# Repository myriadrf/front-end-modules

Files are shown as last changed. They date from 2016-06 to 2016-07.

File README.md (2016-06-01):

# RF Front-end Modules

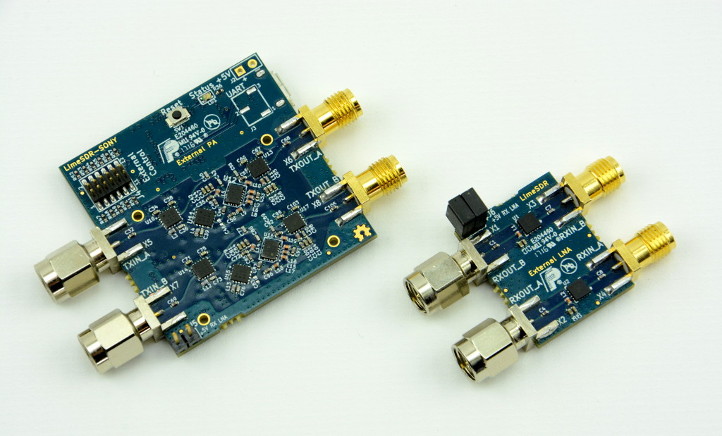
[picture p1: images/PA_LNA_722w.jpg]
Sony PA and TriQuint LNA boards


The [Front-end Modules project](https://myriadrf.org/projects/front-end-modules/) is concerned with creating RF front-end modules, such as PAs, LNAs and filters, that can be used together with an SDR platform in order to create a complete wireless solution.

## Contents

The directory structure is as follows:

      LimeSDR_PA_LNA/           
          firmware/              - firmware for Sony PA
          gui/                   - GUI for firmware PA
          hardware/              - design files for Sony PA and TriQuint LNA boards
          lms_vcp_drivers/       - Windows Virtual COM Port drivers for Sony PA board

      LimeSDR_SAW/<version>/
          BOM/                   - bill of materials spreadsheet
          DRC/                   - Design Rule Verification Report
          ERC/                   - Electrical Rule Check Report
          Gerber/                - Gerber CAM files
          NC Drill/              - Drill files
          Pick Place/            - Pick and place files         

## Licensing

### Hardware

The hardware designs are licensed under a Creative Commons Attribution 3.0 Unported licence.

### Firmware

All original code is provided under the Apache 2.0 License.

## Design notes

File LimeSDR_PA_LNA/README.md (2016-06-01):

# Sony PA and TriQuint LNA modules

## PA

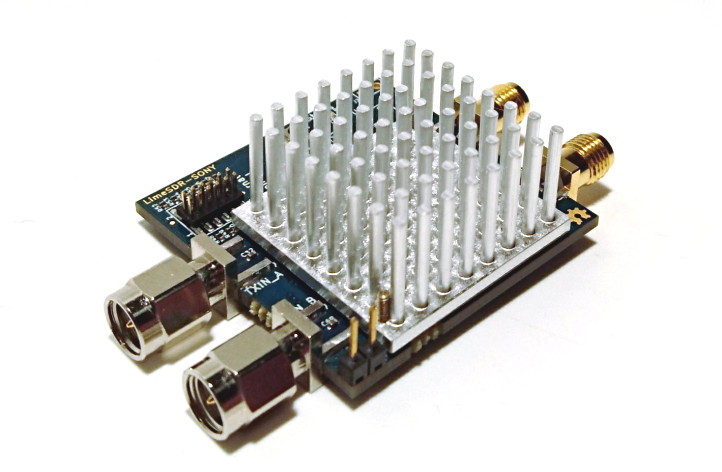
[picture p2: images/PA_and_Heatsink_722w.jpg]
Sony PA with heatsink fitted


## LNA 

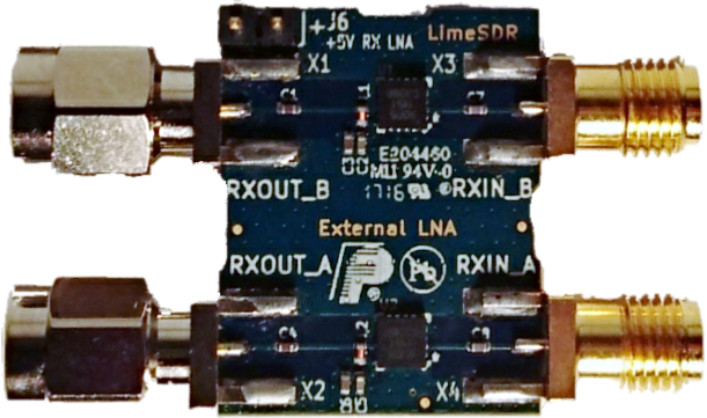
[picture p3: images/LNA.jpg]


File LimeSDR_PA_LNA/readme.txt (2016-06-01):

CONTENTS
========

   I. Description of folders and files

I. Description of folders and files
===================================

  readme.txt				- this file
  firmware/				- USB microcontroller related
   |- bin				- Contains compiled firmware image for USB microcontroller
   |- src				- Contains MCU firmware source files 
  gui/					- Software to control RF-qSpark v1.0 board
   |- paControl.exe			- GUI to control LimeSDR-Sony board
   |- src				- Contains GUI source files
   |- pa_setup                          - Contains SISO and Mode mode settings for PAs and Tuners at Frequencies (GHz): 0.5; 0.8; 1.0; 1.5; ;1.8; 2.1; 2.5; 2.7; 3.0; 3.3; 3.5; 3.8;
  lms_vcp_drivers/			- Windows Virtual COM Port drivers for LimeSDR-Sony board

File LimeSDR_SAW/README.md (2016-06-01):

# SAWNICS SAW filter modules 

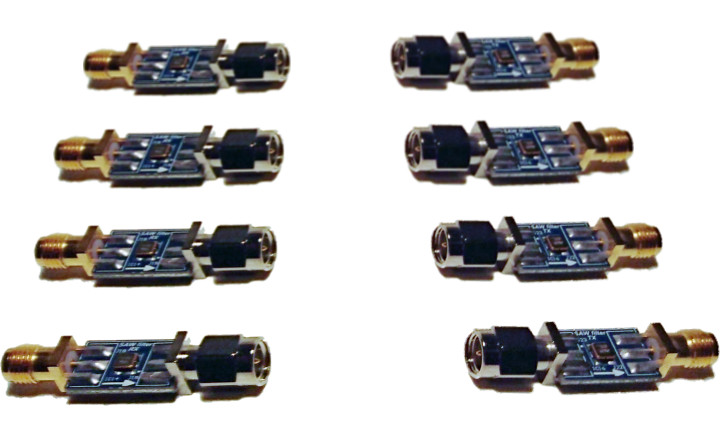
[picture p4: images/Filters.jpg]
TX & RX modules for bands I, II, V, VII


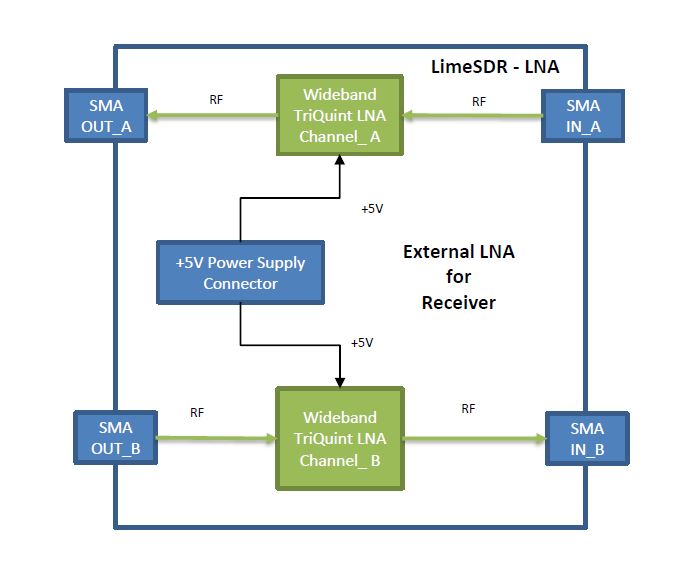
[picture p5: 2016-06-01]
images/LNA_Block_Diagram.jpg

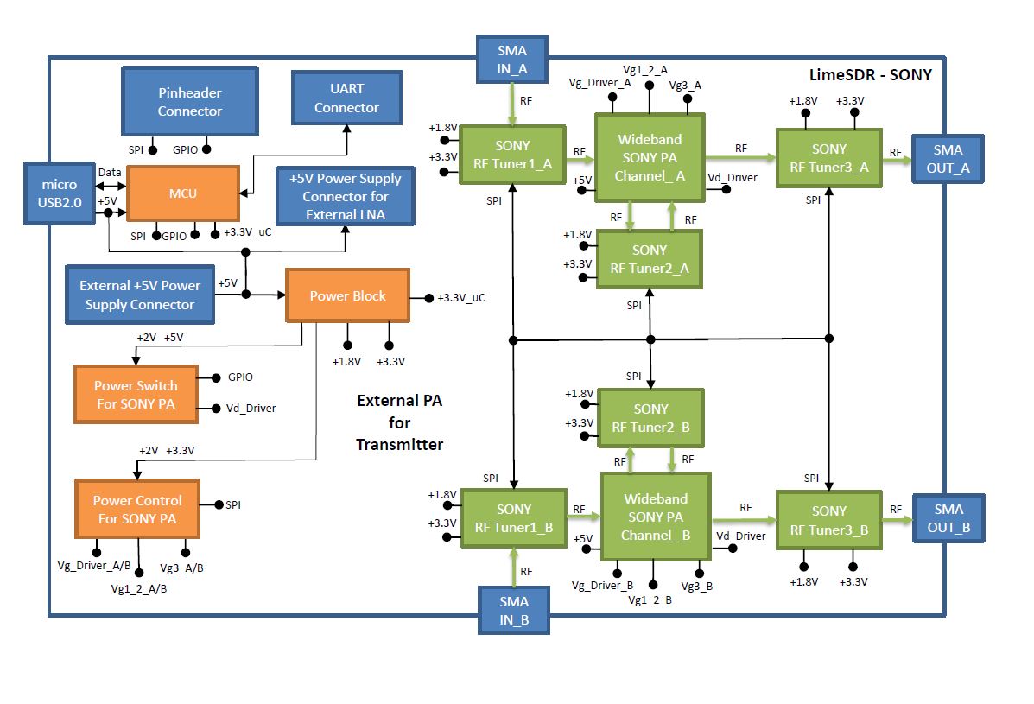
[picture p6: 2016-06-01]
images/PA_Block Diagram.jpg

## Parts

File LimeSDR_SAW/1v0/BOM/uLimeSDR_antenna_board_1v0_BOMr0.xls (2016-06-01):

Item # | Comment | Quantity | Designator | Footprint | Manufacturer | Manufacturer Part Number 1 | Supplier 1 | Supplier Part Number 1 | Part Description | Assembly Info
1 | SAW filter (SAWNICS) RX | 1 | IC1 | SAW_filter_SAWNICS_no_direction
2 | SAW filter (SAWNICS) TX | 1 | IC2 | SAW_filter_SAWNICS_no_direction
3 | SMA_SM_edge | 4 | J1, J2, J3, J4 | SMA_connector_board_edge_SM | Taoglas Limited | EMPCB.SMAFSTJ.B.HT | Digi-Key | 931-1175-ND | CONN SMA JACK STR EDGE MNT

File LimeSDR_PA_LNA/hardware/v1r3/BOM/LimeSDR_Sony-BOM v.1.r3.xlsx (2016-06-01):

ref | part | footprint | name6 | field
R30 | 0R_0402 | SM0402 | Vendor | Farnell
R30 | 0R_0402 | SM0402 | Vendor Part Number | 1469661
R30 | 0R_0402 | SM0402 | Manufacturer | VISHAY DRALORIC
R30 | 0R_0402 | SM0402 | Manufacturer Part Number | CRCW04020000Z0ED
R30 | 0R_0402 | SM0402 | Description | R 0 Ohm 1% 63mW 0402
R30 | 0R_0402 | SM0402 | Component Value | 0R
R12 | 0R_0402 | SM0402 | Vendor | Farnell
R12 | 0R_0402 | SM0402 | Vendor Part Number | 1469661
R12 | 0R_0402 | SM0402 | Manufacturer | VISHAY DRALORIC
R12 | 0R_0402 | SM0402 | Manufacturer Part Number | CRCW04020000Z0ED
R12 | 0R_0402 | SM0402 | Description | R 0 Ohm 1% 63mW 0402
R12 | 0R_0402 | SM0402 | Component Value | 0R
R11 | 0R_0402 | SM0402 | Vendor | Farnell
R11 | 0R_0402 | SM0402 | Vendor Part Number | 1469661
R11 | 0R_0402 | SM0402 | Manufacturer | VISHAY DRALORIC
R11 | 0R_0402 | SM0402 | Manufacturer Part Number | CRCW04020000Z0ED
R11 | 0R_0402 | SM0402 | Description | R 0 Ohm 1% 63mW 0402
R11 | 0R_0402 | SM0402 | Component Value | 0R
R13 | 0R_0402 | SM0402 | Vendor | Farnell
R13 | 0R_0402 | SM0402 | Vendor Part Number | 1469661
R13 | 0R_0402 | SM0402 | Manufacturer | VISHAY DRALORIC
R13 | 0R_0402 | SM0402 | Manufacturer Part Number | CRCW04020000Z0ED
R13 | 0R_0402 | SM0402 | Description | R 0 Ohm 1% 63mW 0402
R13 | 0R_0402 | SM0402 | Component Value | 0R
R20 | 0R_0402 | SM0402 | Vendor | Farnell
R20 | 0R_0402 | SM0402 | Vendor Part Number | 1469661
R20 | 0R_0402 | SM0402 | Manufacturer | VISHAY DRALORIC
R20 | 0R_0402 | SM0402 | Manufacturer Part Number | CRCW04020000Z0ED
R20 | 0R_0402 | SM0402 | Description | R 0 Ohm 1% 63mW 0402
R20 | 0R_0402 | SM0402 | Component Value | 0R
R5 | 0R_0402 | SM0402 | Vendor | Farnell
R5 | 0R_0402 | SM0402 | Vendor Part Number | 1469661
R5 | 0R_0402 | SM0402 | Manufacturer | VISHAY DRALORIC
R5 | 0R_0402 | SM0402 | Manufacturer Part Number | CRCW04020000Z0ED
R5 | 0R_0402 | SM0402 | Description | R 0 Ohm 1% 63mW 0402
R5 | 0R_0402 | SM0402 | Component Value | 0R
R37 | 0R_0402 | SMD0402 | Vendor | Digi-Key
R37 | 0R_0402 | SMD0402 | Vendor Part Number | 311-0.0JRCT-ND
R37 | 0R_0402 | SMD0402 | Manufacturer | Yageo
R37 | 0R_0402 | SMD0402 | Manufacturer Part Number | RC0402JR-070RL
R37 | 0R_0402 | SMD0402 | Description | RES, 0.0 OHM,1/16W, JUMP, 0402 SMD,
R37 | 0R_0402 | SMD0402 | Component Value | 0R
R38 | 0R_0402 | SMD0402 | Vendor | Digi-Key
R38 | 0R_0402 | SMD0402 | Vendor Part Number | 311-0.0JRCT-ND
R38 | 0R_0402 | SMD0402 | Manufacturer | Yageo
R38 | 0R_0402 | SMD0402 | Manufacturer Part Number | RC0402JR-070RL
R38 | 0R_0402 | SMD0402 | Description | RES, 0.0 OHM,1/16W, JUMP, 0402 SMD,
R38 | 0R_0402 | SMD0402 | Component Value | 0R
R39 | 0R_0402 | SMD0402 | Vendor | Digi-Key
R39 | 0R_0402 | SMD0402 | Vendor Part Number | 311-0.0JRCT-ND
R39 | 0R_0402 | SMD0402 | Manufacturer | Yageo
R39 | 0R_0402 | SMD0402 | Manufacturer Part Number | RC0402JR-070RL
R39 | 0R_0402 | SMD0402 | Description | RES, 0.0 OHM,1/16W, JUMP, 0402 SMD,
R39 | 0R_0402 | SMD0402 | Component Value | 0R
R46 | 0R_0402 | SMD0402 | Vendor | Digi-Key
R46 | 0R_0402 | SMD0402 | Vendor Part Number | 311-0.0JRCT-ND
R46 | 0R_0402 | SMD0402 | Manufacturer | Yageo
R46 | 0R_0402 | SMD0402 | Manufacturer Part Number | RC0402JR-070RL
R46 | 0R_0402 | SMD0402 | Description | RES, 0.0 OHM,1/16W, JUMP, 0402 SMD,
R46 | 0R_0402 | SMD0402 | Component Value | 0R
R45 | 0R_0402 | SMD0402 | Vendor | Digi-Key
R45 | 0R_0402 | SMD0402 | Vendor Part Number | 311-0.0JRCT-ND
R45 | 0R_0402 | SMD0402 | Manufacturer | Yageo
R45 | 0R_0402 | SMD0402 | Manufacturer Part Number | RC0402JR-070RL
R45 | 0R_0402 | SMD0402 | Description | RES, 0.0 OHM,1/16W, JUMP, 0402 SMD,
R45 | 0R_0402 | SMD0402 | Component Value | 0R
R61 | 0R_0402 | SMD0402 | Vendor | Digi-Key
R61 | 0R_0402 | SMD0402 | Vendor Part Number | 311-0.0JRCT-ND
R61 | 0R_0402 | SMD0402 | Manufacturer | Yageo
R61 | 0R_0402 | SMD0402 | Manufacturer Part Number | RC0402JR-070RL
R61 | 0R_0402 | SMD0402 | Description | RES, 0.0 OHM,1/16W, JUMP, 0402 SMD,
R61 | 0R_0402 | SMD0402 | Component Value | 0R
R62 | 0R_0402 | SMD0402 | Vendor | Digi-Key
R62 | 0R_0402 | SMD0402 | Vendor Part Number | 311-0.0JRCT-ND
R62 | 0R_0402 | SMD0402 | Manufacturer | Yageo
R62 | 0R_0402 | SMD0402 | Manufacturer Part Number | RC0402JR-070RL
R62 | 0R_0402 | SMD0402 | Description | RES, 0.0 OHM,1/16W, JUMP, 0402 SMD,
R62 | 0R_0402 | SMD0402 | Component Value | 0R
R63 | 0R_0402 | SMD0402 | Vendor | Digi-Key
R63 | 0R_0402 | SMD0402 | Vendor Part Number | 311-0.0JRCT-ND
R63 | 0R_0402 | SMD0402 | Manufacturer | Yageo
R63 | 0R_0402 | SMD0402 | Manufacturer Part Number | RC0402JR-070RL
R63 | 0R_0402 | SMD0402 | Description | RES, 0.0 OHM,1/16W, JUMP, 0402 SMD,
R63 | 0R_0402 | SMD0402 | Component Value | 0R
R58 | 0R_0402 | SMD0402 | Vendor | Digi-Key
R58 | 0R_0402 | SMD0402 | Vendor Part Number | 311-0.0JRCT-ND
R58 | 0R_0402 | SMD0402 | Manufacturer | Yageo
R58 | 0R_0402 | SMD0402 | Manufacturer Part Number | RC0402JR-070RL
R58 | 0R_0402 | SMD0402 | Description | RES, 0.0 OHM,1/16W, JUMP, 0402 SMD,
R58 | 0R_0402 | SMD0402 | Component Value | 0R
R59 | 0R_0402 | SMD0402 | Vendor | Digi-Key
R59 | 0R_0402 | SMD0402 | Vendor Part Number | 311-0.0JRCT-ND
R59 | 0R_0402 | SMD0402 | Manufacturer | Yageo
R59 | 0R_0402 | SMD0402 | Manufacturer Part Number | RC0402JR-070RL
R59 | 0R_0402 | SMD0402 | Description | RES, 0.0 OHM,1/16W, JUMP, 0402 SMD,
R59 | 0R_0402 | SMD0402 | Component Value | 0R
R60 | 0R_0402 | SMD0402 | Vendor | Digi-Key
R60 | 0R_0402 | SMD0402 | Vendor Part Number | 311-0.0JRCT-ND
R60 | 0R_0402 | SMD0402 | Manufacturer | Yageo
R60 | 0R_0402 | SMD0402 | Manufacturer Part Number | RC0402JR-070RL
R60 | 0R_0402 | SMD0402 | Description | RES, 0.0 OHM,1/16W, JUMP, 0402 SMD,
R60 | 0R_0402 | SMD0402 | Component Value | 0R
R64 | 0R_0402 | SMD0402 | Vendor | Digi-Key
R64 | 0R_0402 | SMD0402 | Vendor Part Number | 311-0.0JRCT-ND
R64 | 0R_0402 | SMD0402 | Manufacturer | Yageo
R64 | 0R_0402 | SMD0402 | Manufacturer Part Number | RC0402JR-070RL
R64 | 0R_0402 | SMD0402 | Description | RES, 0.0 OHM,1/16W, JUMP, 0402 SMD,
R64 | 0R_0402 | SMD0402 | Component Value | 0R
R49 | 0R_0402 | SMD0402 | Vendor | Digi-Key
R49 | 0R_0402 | SMD0402 | Vendor Part Number | 311-0.0JRCT-ND
R49 | 0R_0402 | SMD0402 | Manufacturer | Yageo
R49 | 0R_0402 | SMD0402 | Manufacturer Part Number | RC0402JR-070RL
R49 | 0R_0402 | SMD0402 | Description | RES, 0.0 OHM,1/16W, JUMP, 0402 SMD,
R49 | 0R_0402 | SMD0402 | Component Value | 0R
R50 | 0R_0402 | SMD0402 | Vendor | Digi-Key
R50 | 0R_0402 | SMD0402 | Vendor Part Number | 311-0.0JRCT-ND
R50 | 0R_0402 | SMD0402 | Manufacturer | Yageo
R50 | 0R_0402 | SMD0402 | Manufacturer Part Number | RC0402JR-070RL
R50 | 0R_0402 | SMD0402 | Description | RES, 0.0 OHM,1/16W, JUMP, 0402 SMD,
R50 | 0R_0402 | SMD0402 | Component Value | 0R
R51 | 0R_0402 | SMD0402 | Vendor | Digi-Key
R51 | 0R_0402 | SMD0402 | Vendor Part Number | 311-0.0JRCT-ND
R51 | 0R_0402 | SMD0402 | Manufacturer | Yageo
R51 | 0R_0402 | SMD0402 | Manufacturer Part Number | RC0402JR-070RL
R51 | 0R_0402 | SMD0402 | Description | RES, 0.0 OHM,1/16W, JUMP, 0402 SMD,
R51 | 0R_0402 | SMD0402 | Component Value | 0R
R47 | 0R_0402 | SMD0402 | Vendor | Digi-Key
R47 | 0R_0402 | SMD0402 | Vendor Part Number | 311-0.0JRCT-ND
R47 | 0R_0402 | SMD0402 | Manufacturer | Yageo
R47 | 0R_0402 | SMD0402 | Manufacturer Part Number | RC0402JR-070RL
R47 | 0R_0402 | SMD0402 | Description | RES, 0.0 OHM,1/16W, JUMP, 0402 SMD,
R47 | 0R_0402 | SMD0402 | Component Value | 0R
R48 | 0R_0402 | SMD0402 | Vendor | Digi-Key
R48 | 0R_0402 | SMD0402 | Vendor Part Number | 311-0.0JRCT-ND
R48 | 0R_0402 | SMD0402 | Manufacturer | Yageo
R48 | 0R_0402 | SMD0402 | Manufacturer Part Number | RC0402JR-070RL
R48 | 0R_0402 | SMD0402 | Description | RES, 0.0 OHM,1/16W, JUMP, 0402 SMD,
R48 | 0R_0402 | SMD0402 | Component Value | 0R
R54 | 0R_0402 | SMD0402 | Vendor | Digi-Key
R54 | 0R_0402 | SMD0402 | Vendor Part Number | 311-0.0JRCT-ND
R54 | 0R_0402 | SMD0402 | Manufacturer | Yageo
R54 | 0R_0402 | SMD0402 | Manufacturer Part Number | RC0402JR-070RL
R54 | 0R_0402 | SMD0402 | Description | RES, 0.0 OHM,1/16W, JUMP, 0402 SMD,
R54 | 0R_0402 | SMD0402 | Component Value | 0R
R55 | 0R_0402 | SMD0402 | Vendor | Digi-Key
R55 | 0R_0402 | SMD0402 | Vendor Part Number | 311-0.0JRCT-ND
R55 | 0R_0402 | SMD0402 | Manufacturer | Yageo
R55 | 0R_0402 | SMD0402 | Manufacturer Part Number | RC0402JR-070RL
R55 | 0R_0402 | SMD0402 | Description | RES, 0.0 OHM,1/16W, JUMP, 0402 SMD,
R55 | 0R_0402 | SMD0402 | Component Value | 0R
R56 | 0R_0402 | SMD0402 | Vendor | Digi-Key
R56 | 0R_0402 | SMD0402 | Vendor Part Number | 311-0.0JRCT-ND
R56 | 0R_0402 | SMD0402 | Manufacturer | Yageo
R56 | 0R_0402 | SMD0402 | Manufacturer Part Number | RC0402JR-070RL
R56 | 0R_0402 | SMD0402 | Description | RES, 0.0 OHM,1/16W, JUMP, 0402 SMD,
R56 | 0R_0402 | SMD0402 | Component Value | 0R
R52 | 0R_0402 | SMD0402 | Vendor | Digi-Key
R52 | 0R_0402 | SMD0402 | Vendor Part Number | 311-0.0JRCT-ND
R52 | 0R_0402 | SMD0402 | Manufacturer | Yageo
R52 | 0R_0402 | SMD0402 | Manufacturer Part Number | RC0402JR-070RL
R52 | 0R_0402 | SMD0402 | Description | RES, 0.0 OHM,1/16W, JUMP, 0402 SMD,
R52 | 0R_0402 | SMD0402 | Component Value | 0R
R53 | 0R_0402 | SMD0402 | Vendor | Digi-Key
R53 | 0R_0402 | SMD0402 | Vendor Part Number | 311-0.0JRCT-ND
R53 | 0R_0402 | SMD0402 | Manufacturer | Yageo
R53 | 0R_0402 | SMD0402 | Manufacturer Part Number | RC0402JR-070RL
R53 | 0R_0402 | SMD0402 | Description | RES, 0.0 OHM,1/16W, JUMP, 0402 SMD,
R53 | 0R_0402 | SMD0402 | Component Value | 0R
R57 | 0R_0402 | SMD0402 | Vendor | Digi-Key
R57 | 0R_0402 | SMD0402 | Vendor Part Number | 311-0.0JRCT-ND
R57 | 0R_0402 | SMD0402 | Manufacturer | Yageo
R57 | 0R_0402 | SMD0402 | Manufacturer Part Number | RC0402JR-070RL
R57 | 0R_0402 | SMD0402 | Description | RES, 0.0 OHM,1/16W, JUMP, 0402 SMD,
R57 | 0R_0402 | SMD0402 | Component Value | 0R
R21 | 0R_0402_NF | R_SM0402 | Vendor | Digi-Key
R21 | 0R_0402_NF | R_SM0402 | Vendor Part Number | 311-0.0JRCT-ND
R21 | 0R_0402_NF | R_SM0402 | Manufacturer | Yageo
R21 | 0R_0402_NF | R_SM0402 | Manufacturer Part Number | RC0402JR-070RL
R21 | 0R_0402_NF | R_SM0402 | Description | RES, 0.0 OHM,1/16W, JUMP, 0402 SMD,
R21 | 0R_0402_NF | R_SM0402 | Component Value | 0R
R21 | 0R_0402_NF | R_SM0402 | Install | NF
R21 | 0R_0402_NF | R_SM0402 | Assemble | NOFIT
R9 | 0R_0402_NF | R_SM0402 | Vendor | Digi-Key
R9 | 0R_0402_NF | R_SM0402 | Vendor Part Number | 311-0.0JRCT-ND
R9 | 0R_0402_NF | R_SM0402 | Manufacturer | Yageo
R9 | 0R_0402_NF | R_SM0402 | Manufacturer Part Number | RC0402JR-070RL
R9 | 0R_0402_NF | R_SM0402 | Description | RES, 0.0 OHM,1/16W, JUMP, 0402 SMD,
R9 | 0R_0402_NF | R_SM0402 | Component Value | 0R
R9 | 0R_0402_NF | R_SM0402 | Install | NF
R9 | 0R_0402_NF | R_SM0402 | Assemble | NOFIT
L3 | 1.0nH_0402 | L_SM0402 | Vendor | Coilcraft
L3 | 1.0nH_0402 | L_SM0402 | Vendor Part Number | 0402HP-1N0XJLU
L3 | 1.0nH_0402 | L_SM0402 | Manufacturer | Coilcraft
L3 | 1.0nH_0402 | L_SM0402 | Manufacturer Part Number | 0402HP-1N0XJLU
L3 | 1.0nH_0402 | L_SM0402 | Description | Inductor, 1nH, 0402, 5%,
L3 | 1.0nH_0402 | L_SM0402 | Component Value | 1nH
L12 | 1.0nH_0402 | L_SM0402 | Vendor | Coilcraft
L12 | 1.0nH_0402 | L_SM0402 | Vendor Part Number | 0402HP-1N0XJLU
L12 | 1.0nH_0402 | L_SM0402 | Manufacturer | Coilcraft
L12 | 1.0nH_0402 | L_SM0402 | Manufacturer Part Number | 0402HP-1N0XJLU
L12 | 1.0nH_0402 | L_SM0402 | Description | Inductor, 1nH, 0402, 5%,
L12 | 1.0nH_0402 | L_SM0402 | Component Value | 1nH
C2 | 100nF_0402 | SMD0402 | Vendor | DigiKey
C2 | 100nF_0402 | SMD0402 | Vendor Part Number | 311-1047-1-ND
C2 | 100nF_0402 | SMD0402 | Manufacturer | Yageo
C2 | 100nF_0402 | SMD0402 | Manufacturer Part Number | CC0402ZRY5V7BB104
C2 | 100nF_0402 | SMD0402 | Description | CAP, CER, 0.1UF, 16V, Y5V, 0402,
C2 | 100nF_0402 | SMD0402 | Component Value | 100nF
C5 | 100nF_0402 | SMD0402 | Vendor | DigiKey
C5 | 100nF_0402 | SMD0402 | Vendor Part Number | 311-1047-1-ND
C5 | 100nF_0402 | SMD0402 | Manufacturer | Yageo
C5 | 100nF_0402 | SMD0402 | Manufacturer Part Number | CC0402ZRY5V7BB104
C5 | 100nF_0402 | SMD0402 | Description | CAP, CER, 0.1UF, 16V, Y5V, 0402,
C5 | 100nF_0402 | SMD0402 | Component Value | 100nF
C28 | 100nF_0402 | SMD0402 | Vendor | DigiKey
C28 | 100nF_0402 | SMD0402 | Vendor Part Number | 311-1047-1-ND
C28 | 100nF_0402 | SMD0402 | Manufacturer | Yageo
C28 | 100nF_0402 | SMD0402 | Manufacturer Part Number | CC0402ZRY5V7BB104
C28 | 100nF_0402 | SMD0402 | Description | CAP, CER, 0.1UF, 16V, Y5V, 0402,
C28 | 100nF_0402 | SMD0402 | Component Value | 100nF
C25 | 100nF_0402 | SMD0402 | Vendor | DigiKey
C25 | 100nF_0402 | SMD0402 | Vendor Part Number | 311-1047-1-ND
C25 | 100nF_0402 | SMD0402 | Manufacturer | Yageo
C25 | 100nF_0402 | SMD0402 | Manufacturer Part Number | CC0402ZRY5V7BB104
C25 | 100nF_0402 | SMD0402 | Description | CAP, CER, 0.1UF, 16V, Y5V, 0402,
C25 | 100nF_0402 | SMD0402 | Component Value | 100nF
C17 | 100nF_0402 | SMD0402 | Vendor | DigiKey
C17 | 100nF_0402 | SMD0402 | Vendor Part Number | 311-1047-1-ND
C17 | 100nF_0402 | SMD0402 | Manufacturer | Yageo
C17 | 100nF_0402 | SMD0402 | Manufacturer Part Number | CC0402ZRY5V7BB104
C17 | 100nF_0402 | SMD0402 | Description | CAP, CER, 0.1UF, 16V, Y5V, 0402,
C17 | 100nF_0402 | SMD0402 | Component Value | 100nF
C34 | 100nF_0402 | SMD0402 | Vendor | DigiKey
C34 | 100nF_0402 | SMD0402 | Vendor Part Number | 311-1047-1-ND
C34 | 100nF_0402 | SMD0402 | Manufacturer | Yageo
C34 | 100nF_0402 | SMD0402 | Manufacturer Part Number | CC0402ZRY5V7BB104
C34 | 100nF_0402 | SMD0402 | Description | CAP, CER, 0.1UF, 16V, Y5V, 0402,
C34 | 100nF_0402 | SMD0402 | Component Value | 100nF
C37 | 100nF_0402 | SMD0402 | Vendor | DigiKey
C37 | 100nF_0402 | SMD0402 | Vendor Part Number | 311-1047-1-ND
C37 | 100nF_0402 | SMD0402 | Manufacturer | Yageo
C37 | 100nF_0402 | SMD0402 | Manufacturer Part Number | CC0402ZRY5V7BB104
C37 | 100nF_0402 | SMD0402 | Description | CAP, CER, 0.1UF, 16V, Y5V, 0402,
C37 | 100nF_0402 | SMD0402 | Component Value | 100nF
C60 | 100nF_0402 | SMD0402 | Vendor | DigiKey
C60 | 100nF_0402 | SMD0402 | Vendor Part Number | 311-1047-1-ND
C60 | 100nF_0402 | SMD0402 | Manufacturer | Yageo
C60 | 100nF_0402 | SMD0402 | Manufacturer Part Number | CC0402ZRY5V7BB104
C60 | 100nF_0402 | SMD0402 | Description | CAP, CER, 0.1UF, 16V, Y5V, 0402,
C60 | 100nF_0402 | SMD0402 | Component Value | 100nF
C38 | 100nF_0402 | SMD0402 | Vendor | DigiKey
C38 | 100nF_0402 | SMD0402 | Vendor Part Number | 311-1047-1-ND
C38 | 100nF_0402 | SMD0402 | Manufacturer | Yageo
C38 | 100nF_0402 | SMD0402 | Manufacturer Part Number | CC0402ZRY5V7BB104
C38 | 100nF_0402 | SMD0402 | Description | CAP, CER, 0.1UF, 16V, Y5V, 0402,
C38 | 100nF_0402 | SMD0402 | Component Value | 100nF
C41 | 100nF_0402 | SMD0402 | Vendor | DigiKey
C41 | 100nF_0402 | SMD0402 | Vendor Part Number | 311-1047-1-ND
C41 | 100nF_0402 | SMD0402 | Manufacturer | Yageo
C41 | 100nF_0402 | SMD0402 | Manufacturer Part Number | CC0402ZRY5V7BB104
C41 | 100nF_0402 | SMD0402 | Description | CAP, CER, 0.1UF, 16V, Y5V, 0402,
C41 | 100nF_0402 | SMD0402 | Component Value | 100nF
C67 | 100nF_0402 | SMD0402 | Vendor | DigiKey
C67 | 100nF_0402 | SMD0402 | Vendor Part Number | 311-1047-1-ND
C67 | 100nF_0402 | SMD0402 | Manufacturer | Yageo
C67 | 100nF_0402 | SMD0402 | Manufacturer Part Number | CC0402ZRY5V7BB104
C67 | 100nF_0402 | SMD0402 | Description | CAP, CER, 0.1UF, 16V, Y5V, 0402,
C67 | 100nF_0402 | SMD0402 | Component Value | 100nF
C71 | 100nF_0402 | SMD0402 | Vendor | DigiKey
C71 | 100nF_0402 | SMD0402 | Vendor Part Number | 311-1047-1-ND
C71 | 100nF_0402 | SMD0402 | Manufacturer | Yageo
C71 | 100nF_0402 | SMD0402 | Manufacturer Part Number | CC0402ZRY5V7BB104
C71 | 100nF_0402 | SMD0402 | Description | CAP, CER, 0.1UF, 16V, Y5V, 0402,
C71 | 100nF_0402 | SMD0402 | Component Value | 100nF
C74 | 100nF_0402 | SMD0402 | Vendor | DigiKey
C74 | 100nF_0402 | SMD0402 | Vendor Part Number | 311-1047-1-ND
C74 | 100nF_0402 | SMD0402 | Manufacturer | Yageo
C74 | 100nF_0402 | SMD0402 | Manufacturer Part Number | CC0402ZRY5V7BB104
C74 | 100nF_0402 | SMD0402 | Description | CAP, CER, 0.1UF, 16V, Y5V, 0402,
C74 | 100nF_0402 | SMD0402 | Component Value | 100nF
C95 | 100nF_0402 | SMD0402 | Vendor | DigiKey
C95 | 100nF_0402 | SMD0402 | Vendor Part Number | 311-1047-1-ND
C95 | 100nF_0402 | SMD0402 | Manufacturer | Yageo
C95 | 100nF_0402 | SMD0402 | Manufacturer Part Number | CC0402ZRY5V7BB104
C95 | 100nF_0402 | SMD0402 | Description | CAP, CER, 0.1UF, 16V, Y5V, 0402,
C95 | 100nF_0402 | SMD0402 | Component Value | 100nF
C75 | 100nF_0402 | SMD0402 | Vendor | DigiKey
C75 | 100nF_0402 | SMD0402 | Vendor Part Number | 311-1047-1-ND
C75 | 100nF_0402 | SMD0402 | Manufacturer | Yageo
C75 | 100nF_0402 | SMD0402 | Manufacturer Part Number | CC0402ZRY5V7BB104
C75 | 100nF_0402 | SMD0402 | Description | CAP, CER, 0.1UF, 16V, Y5V, 0402,
C75 | 100nF_0402 | SMD0402 | Component Value | 100nF
C78 | 100nF_0402 | SMD0402 | Vendor | DigiKey
C78 | 100nF_0402 | SMD0402 | Vendor Part Number | 311-1047-1-ND
C78 | 100nF_0402 | SMD0402 | Manufacturer | Yageo
C78 | 100nF_0402 | SMD0402 | Manufacturer Part Number | CC0402ZRY5V7BB104
C78 | 100nF_0402 | SMD0402 | Description | CAP, CER, 0.1UF, 16V, Y5V, 0402,
C78 | 100nF_0402 | SMD0402 | Component Value | 100nF
C103 | 100nF_0402 | SMD0402 | Vendor | DigiKey
C103 | 100nF_0402 | SMD0402 | Vendor Part Number | 311-1047-1-ND
C103 | 100nF_0402 | SMD0402 | Manufacturer | Yageo
C103 | 100nF_0402 | SMD0402 | Manufacturer Part Number | CC0402ZRY5V7BB104
C103 | 100nF_0402 | SMD0402 | Description | CAP, CER, 0.1UF, 16V, Y5V, 0402,
C103 | 100nF_0402 | SMD0402 | Component Value | 100nF
C109 | 100nF_0402 | SMD0402 | Vendor | DigiKey
C109 | 100nF_0402 | SMD0402 | Vendor Part Number | 311-1047-1-ND
C109 | 100nF_0402 | SMD0402 | Manufacturer | Yageo
C109 | 100nF_0402 | SMD0402 | Manufacturer Part Number | CC0402ZRY5V7BB104
C109 | 100nF_0402 | SMD0402 | Description | CAP, CER, 0.1UF, 16V, Y5V, 0402,
C109 | 100nF_0402 | SMD0402 | Component Value | 100nF
C107 | 100nF_0402 | SMD0402 | Vendor | DigiKey
C107 | 100nF_0402 | SMD0402 | Vendor Part Number | 311-1047-1-ND
C107 | 100nF_0402 | SMD0402 | Manufacturer | Yageo
C107 | 100nF_0402 | SMD0402 | Manufacturer Part Number | CC0402ZRY5V7BB104
C107 | 100nF_0402 | SMD0402 | Description | CAP, CER, 0.1UF, 16V, Y5V, 0402,
C107 | 100nF_0402 | SMD0402 | Component Value | 100nF
C111 | 100nF_0402 | SMD0402 | Vendor | DigiKey
C111 | 100nF_0402 | SMD0402 | Vendor Part Number | 311-1047-1-ND
C111 | 100nF_0402 | SMD0402 | Manufacturer | Yageo
C111 | 100nF_0402 | SMD0402 | Manufacturer Part Number | CC0402ZRY5V7BB104
C111 | 100nF_0402 | SMD0402 | Description | CAP, CER, 0.1UF, 16V, Y5V, 0402,
C111 | 100nF_0402 | SMD0402 | Component Value | 100nF
C114 | 100nF_0402 | SMD0402 | Vendor | DigiKey
C114 | 100nF_0402 | SMD0402 | Vendor Part Number | 311-1047-1-ND
C114 | 100nF_0402 | SMD0402 | Manufacturer | Yageo
C114 | 100nF_0402 | SMD0402 | Manufacturer Part Number | CC0402ZRY5V7BB104
C114 | 100nF_0402 | SMD0402 | Description | CAP, CER, 0.1UF, 16V, Y5V, 0402,
C114 | 100nF_0402 | SMD0402 | Component Value | 100nF
C115 | 100nF_0402 | SMD0402 | Vendor | DigiKey
C115 | 100nF_0402 | SMD0402 | Vendor Part Number | 311-1047-1-ND
C115 | 100nF_0402 | SMD0402 | Manufacturer | Yageo
C115 | 100nF_0402 | SMD0402 | Manufacturer Part Number | CC0402ZRY5V7BB104
C115 | 100nF_0402 | SMD0402 | Description | CAP, CER, 0.1UF, 16V, Y5V, 0402,
C115 | 100nF_0402 | SMD0402 | Component Value | 100nF
C7 | 100pF_0402 | SMD0402 | Vendor | Digi-Key
C7 | 100pF_0402 | SMD0402 | Vendor Part Number | 311-1024-1-ND
C7 | 100pF_0402 | SMD0402 | Manufacturer | Yageo
C7 | 100pF_0402 | SMD0402 | Manufacturer Part Number | CC0402JRNPO9BN101
C7 | 100pF_0402 | SMD0402 | Description | CAP CER, 100PF, 50V, 5%, NPO, 0402,
C7 | 100pF_0402 | SMD0402 | Component Value | 100pF
C8 | 100pF_0402 | SMD0402 | Vendor | Digi-Key
C8 | 100pF_0402 | SMD0402 | Vendor Part Number | 311-1024-1-ND
C8 | 100pF_0402 | SMD0402 | Manufacturer | Yageo
C8 | 100pF_0402 | SMD0402 | Manufacturer Part Number | CC0402JRNPO9BN101
C8 | 100pF_0402 | SMD0402 | Description | CAP CER, 100PF, 50V, 5%, NPO, 0402,
C8 | 100pF_0402 | SMD0402 | Component Value | 100pF
C65 | 100pF_0402 | SMD0402 | Vendor | Digi-Key
C65 | 100pF_0402 | SMD0402 | Vendor Part Number | 311-1024-1-ND
C65 | 100pF_0402 | SMD0402 | Manufacturer | Yageo
C65 | 100pF_0402 | SMD0402 | Manufacturer Part Number | CC0402JRNPO9BN101
C65 | 100pF_0402 | SMD0402 | Description | CAP CER, 100PF, 50V, 5%, NPO, 0402,
C65 | 100pF_0402 | SMD0402 | Component Value | 100pF
C98 | 100pF_0402 | SMD0402 | Vendor | Digi-Key
C98 | 100pF_0402 | SMD0402 | Vendor Part Number | 311-1024-1-ND
C98 | 100pF_0402 | SMD0402 | Manufacturer | Yageo
C98 | 100pF_0402 | SMD0402 | Manufacturer Part Number | CC0402JRNPO9BN101
C98 | 100pF_0402 | SMD0402 | Description | CAP CER, 100PF, 50V, 5%, NPO, 0402,
C98 | 100pF_0402 | SMD0402 | Component Value | 100pF
R36 | 100R_0402 | SMD0402 | Vendor | Digi-Key
R36 | 100R_0402 | SMD0402 | Vendor Part Number | 311-100GRCT-ND
R36 | 100R_0402 | SMD0402 | Manufacturer | Yageo
R36 | 100R_0402 | SMD0402 | Manufacturer Part Number | RC0603JR-07100RL
R36 | 100R_0402 | SMD0402 | Description | RES, 100 OHM, 1/10W, 5%, 0603, SMD,
R36 | 100R_0402 | SMD0402 | Component Value | 100R
R10 | 10K_0402 | SMD0402 | Vendor | Digi-Key
R10 | 10K_0402 | SMD0402 | Vendor Part Number | RMCF0402FT10K0CT-ND
R10 | 10K_0402 | SMD0402 | Manufacturer | Stackpole Electronics Inc
R10 | 10K_0402 | SMD0402 | Manufacturer Part Number | RMCF0402FT10K0
R10 | 10K_0402 | SMD0402 | Description | RES 10K OHM 1/16W 1% 0402
R10 | 10K_0402 | SMD0402 | Component Value | 10K
R1 | 10K_0402 | SMD0402 | Vendor | Digi-Key
R1 | 10K_0402 | SMD0402 | Vendor Part Number | RMCF0402FT10K0CT-ND
R1 | 10K_0402 | SMD0402 | Manufacturer | Stackpole Electronics Inc
R1 | 10K_0402 | SMD0402 | Manufacturer Part Number | RMCF0402FT10K0
R1 | 10K_0402 | SMD0402 | Description | RES 10K OHM 1/16W 1% 0402
R1 | 10K_0402 | SMD0402 | Component Value | 10K
R22 | 10K_0402 | SMD0402 | Vendor | Digi-Key
R22 | 10K_0402 | SMD0402 | Vendor Part Number | RMCF0402FT10K0CT-ND
R22 | 10K_0402 | SMD0402 | Manufacturer | Stackpole Electronics Inc
R22 | 10K_0402 | SMD0402 | Manufacturer Part Number | RMCF0402FT10K0
R22 | 10K_0402 | SMD0402 | Description | RES 10K OHM 1/16W 1% 0402
R22 | 10K_0402 | SMD0402 | Component Value | 10K
R44 | 10K_0402 | SMD0402 | Vendor | Digi-Key
R44 | 10K_0402 | SMD0402 | Vendor Part Number | RMCF0402FT10K0CT-ND
R44 | 10K_0402 | SMD0402 | Manufacturer | Stackpole Electronics Inc
R44 | 10K_0402 | SMD0402 | Manufacturer Part Number | RMCF0402FT10K0
R44 | 10K_0402 | SMD0402 | Description | RES 10K OHM 1/16W 1% 0402
R44 | 10K_0402 | SMD0402 | Component Value | 10K
C44 | 10nF_0402 | SM0402 | Vendor | DigiKey
C44 | 10nF_0402 | SM0402 | Vendor Part Number | 311-1349-1-ND
C44 | 10nF_0402 | SM0402 | Manufacturer | Yageo
C44 | 10nF_0402 | SM0402 | Manufacturer Part Number | CC0402KRX7R9BB103
C44 | 10nF_0402 | SM0402 | Description | CAP CER, 10000PF, 50V, 10%, X7R, 0402,
C44 | 10nF_0402 | SM0402 | Component Value | 10nF
C50 | 10nF_0402 | SM0402 | Vendor | DigiKey
C50 | 10nF_0402 | SM0402 | Vendor Part Number | 311-1349-1-ND
C50 | 10nF_0402 | SM0402 | Manufacturer | Yageo
C50 | 10nF_0402 | SM0402 | Manufacturer Part Number | CC0402KRX7R9BB103
C50 | 10nF_0402 | SM0402 | Description | CAP CER, 10000PF, 50V, 10%, X7R, 0402,
C50 | 10nF_0402 | SM0402 | Component Value | 10nF
C61 | 10nF_0402 | SM0402 | Vendor | DigiKey
C61 | 10nF_0402 | SM0402 | Vendor Part Number | 311-1349-1-ND
C61 | 10nF_0402 | SM0402 | Manufacturer | Yageo
C61 | 10nF_0402 | SM0402 | Manufacturer Part Number | CC0402KRX7R9BB103
C61 | 10nF_0402 | SM0402 | Description | CAP CER, 10000PF, 50V, 10%, X7R, 0402,
C61 | 10nF_0402 | SM0402 | Component Value | 10nF
C54 | 10nF_0402 | SM0402 | Vendor | DigiKey
C54 | 10nF_0402 | SM0402 | Vendor Part Number | 311-1349-1-ND
C54 | 10nF_0402 | SM0402 | Manufacturer | Yageo
C54 | 10nF_0402 | SM0402 | Manufacturer Part Number | CC0402KRX7R9BB103
C54 | 10nF_0402 | SM0402 | Description | CAP CER, 10000PF, 50V, 10%, X7R, 0402,
C54 | 10nF_0402 | SM0402 | Component Value | 10nF
C64 | 10nF_0402 | SM0402 | Vendor | DigiKey
C64 | 10nF_0402 | SM0402 | Vendor Part Number | 311-1349-1-ND
C64 | 10nF_0402 | SM0402 | Manufacturer | Yageo
C64 | 10nF_0402 | SM0402 | Manufacturer Part Number | CC0402KRX7R9BB103
C64 | 10nF_0402 | SM0402 | Description | CAP CER, 10000PF, 50V, 10%, X7R, 0402,
C64 | 10nF_0402 | SM0402 | Component Value | 10nF
C81 | 10nF_0402 | SM0402 | Vendor | DigiKey
C81 | 10nF_0402 | SM0402 | Vendor Part Number | 311-1349-1-ND
C81 | 10nF_0402 | SM0402 | Manufacturer | Yageo
C81 | 10nF_0402 | SM0402 | Manufacturer Part Number | CC0402KRX7R9BB103
C81 | 10nF_0402 | SM0402 | Description | CAP CER, 10000PF, 50V, 10%, X7R, 0402,
C81 | 10nF_0402 | SM0402 | Component Value | 10nF
C87 | 10nF_0402 | SM0402 | Vendor | DigiKey
C87 | 10nF_0402 | SM0402 | Vendor Part Number | 311-1349-1-ND
C87 | 10nF_0402 | SM0402 | Manufacturer | Yageo
C87 | 10nF_0402 | SM0402 | Manufacturer Part Number | CC0402KRX7R9BB103
C87 | 10nF_0402 | SM0402 | Description | CAP CER, 10000PF, 50V, 10%, X7R, 0402,
C87 | 10nF_0402 | SM0402 | Component Value | 10nF
C99 | 10nF_0402 | SM0402 | Vendor | DigiKey
C99 | 10nF_0402 | SM0402 | Vendor Part Number | 311-1349-1-ND
C99 | 10nF_0402 | SM0402 | Manufacturer | Yageo
C99 | 10nF_0402 | SM0402 | Manufacturer Part Number | CC0402KRX7R9BB103
C99 | 10nF_0402 | SM0402 | Description | CAP CER, 10000PF, 50V, 10%, X7R, 0402,
C99 | 10nF_0402 | SM0402 | Component Value | 10nF
C93 | 10nF_0402 | SM0402 | Vendor | DigiKey
C93 | 10nF_0402 | SM0402 | Vendor Part Number | 311-1349-1-ND
C93 | 10nF_0402 | SM0402 | Manufacturer | Yageo
C93 | 10nF_0402 | SM0402 | Manufacturer Part Number | CC0402KRX7R9BB103
C93 | 10nF_0402 | SM0402 | Description | CAP CER, 10000PF, 50V, 10%, X7R, 0402,
C93 | 10nF_0402 | SM0402 | Component Value | 10nF
C102 | 10nF_0402 | SM0402 | Vendor | DigiKey
C102 | 10nF_0402 | SM0402 | Vendor Part Number | 311-1349-1-ND
C102 | 10nF_0402 | SM0402 | Manufacturer | Yageo
C102 | 10nF_0402 | SM0402 | Manufacturer Part Number | CC0402KRX7R9BB103
C102 | 10nF_0402 | SM0402 | Description | CAP CER, 10000PF, 50V, 10%, X7R, 0402,
C102 | 10nF_0402 | SM0402 | Component Value | 10nF
C106 | 10nF_0402 | SM0402 | Vendor | DigiKey
C106 | 10nF_0402 | SM0402 | Vendor Part Number | 311-1349-1-ND
C106 | 10nF_0402 | SM0402 | Manufacturer | Yageo
C106 | 10nF_0402 | SM0402 | Manufacturer Part Number | CC0402KRX7R9BB103
C106 | 10nF_0402 | SM0402 | Description | CAP CER, 10000PF, 50V, 10%, X7R, 0402,
C106 | 10nF_0402 | SM0402 | Component Value | 10nF
C39 | 10pF_0402 | SMD0402 | Vendor | Digi-Key
C39 | 10pF_0402 | SMD0402 | Vendor Part Number | 311-1014-1-ND
C39 | 10pF_0402 | SMD0402 | Manufacturer | Yageo
C39 | 10pF_0402 | SMD0402 | Manufacturer Part Number | CC0402JRNPO9BN100
C39 | 10pF_0402 | SMD0402 | Description | CAP, CER, 10PF, 50V, 5%, NPO, 0402,
C39 | 10pF_0402 | SMD0402 | Component Value | 10pF
C36 | 10pF_0402 | SMD0402 | Vendor | Digi-Key
C36 | 10pF_0402 | SMD0402 | Vendor Part Number | 311-1014-1-ND
C36 | 10pF_0402 | SMD0402 | Manufacturer | Yageo
C36 | 10pF_0402 | SMD0402 | Manufacturer Part Number | CC0402JRNPO9BN100
C36 | 10pF_0402 | SMD0402 | Description | CAP, CER, 10PF, 50V, 5%, NPO, 0402,
C36 | 10pF_0402 | SMD0402 | Component Value | 10pF
C43 | 10pF_0402 | SMD0402 | Vendor | Digi-Key
C43 | 10pF_0402 | SMD0402 | Vendor Part Number | 311-1014-1-ND
C43 | 10pF_0402 | SMD0402 | Manufacturer | Yageo
C43 | 10pF_0402 | SMD0402 | Manufacturer Part Number | CC0402JRNPO9BN100
C43 | 10pF_0402 | SMD0402 | Description | CAP, CER, 10PF, 50V, 5%, NPO, 0402,
C43 | 10pF_0402 | SMD0402 | Component Value | 10pF
C73 | 10pF_0402 | SMD0402 | Vendor | Digi-Key
C73 | 10pF_0402 | SMD0402 | Vendor Part Number | 311-1014-1-ND
C73 | 10pF_0402 | SMD0402 | Manufacturer | Yageo
C73 | 10pF_0402 | SMD0402 | Manufacturer Part Number | CC0402JRNPO9BN100
C73 | 10pF_0402 | SMD0402 | Description | CAP, CER, 10PF, 50V, 5%, NPO, 0402,
C73 | 10pF_0402 | SMD0402 | Component Value | 10pF
C76 | 10pF_0402 | SMD0402 | Vendor | Digi-Key
C76 | 10pF_0402 | SMD0402 | Vendor Part Number | 311-1014-1-ND
C76 | 10pF_0402 | SMD0402 | Manufacturer | Yageo
C76 | 10pF_0402 | SMD0402 | Manufacturer Part Number | CC0402JRNPO9BN100
C76 | 10pF_0402 | SMD0402 | Description | CAP, CER, 10PF, 50V, 5%, NPO, 0402,
C76 | 10pF_0402 | SMD0402 | Component Value | 10pF
C80 | 10pF_0402 | SMD0402 | Vendor | Digi-Key
C80 | 10pF_0402 | SMD0402 | Vendor Part Number | 311-1014-1-ND
C80 | 10pF_0402 | SMD0402 | Manufacturer | Yageo
C80 | 10pF_0402 | SMD0402 | Manufacturer Part Number | CC0402JRNPO9BN100
C80 | 10pF_0402 | SMD0402 | Description | CAP, CER, 10PF, 50V, 5%, NPO, 0402,
C80 | 10pF_0402 | SMD0402 | Component Value | 10pF
C23 | 10uF_0402 | SMD0402 | Vendor | Digi-Key
C23 | 10uF_0402 | SMD0402 | Vendor Part Number | 1276-1450-1-ND
C23 | 10uF_0402 | SMD0402 | Manufacturer | Samsung Electro-Mechanics America, Inc
C23 | 10uF_0402 | SMD0402 | Manufacturer Part Number | CL05A106MP5NUNC
C23 | 10uF_0402 | SMD0402 | Description | CAP CER, 10UF, 10V, 20%, X5R, 0402,
C23 | 10uF_0402 | SMD0402 | Component Value | 10uF
C15 | 10uF_0402 | SMD0402 | Vendor | Digi-Key
C15 | 10uF_0402 | SMD0402 | Vendor Part Number | 1276-1450-1-ND
C15 | 10uF_0402 | SMD0402 | Manufacturer | Samsung Electro-Mechanics America, Inc
C15 | 10uF_0402 | SMD0402 | Manufacturer Part Number | CL05A106MP5NUNC
C15 | 10uF_0402 | SMD0402 | Description | CAP CER, 10UF, 10V, 20%, X5R, 0402,
C15 | 10uF_0402 | SMD0402 | Component Value | 10uF
C108 | 10uF_1206 | SMD1206 | Vendor | Digi-Key
C108 | 10uF_1206 | SMD1206 | Vendor Part Number | 311-1376-1-ND
C108 | 10uF_1206 | SMD1206 | Manufacturer | Yageo
C108 | 10uF_1206 | SMD1206 | Manufacturer Part Number | CC1206ZKY5V7BB106
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

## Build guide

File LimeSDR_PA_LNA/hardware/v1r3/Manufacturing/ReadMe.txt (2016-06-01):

Contact Details
---------------

Lime Microsystems Ltd.
Surrey Technology Centre, Occam Road,             
The Surrey Research Park,
Guilford, Surrey.
GU2 7YG 
United Kingdom

http: www.limemicro.com

contact person:
  Ignas Skudrcikas
  email: i.skudrickas@limemicro.com

Licence: 
Copyright 2016 Lime Microsystems, Ltd.
WORK IS COVERED UNDER A CREATIVE COMMONS LICENSE (CC BY 3.0)

Board Description
-----------------

board designation       : LimeSDR-Sony Board v.1 r.3
board type              : Lead Free
board size              : 51.9 mm x 80.1 mm
board thickness         : 1.6 mm +/- 10 %
board material          : IT-180A

number of layers        : 6

Top layer copper foil thickness: 0.333+plating
Dielectric thickness between Top layer and 2nd layer: 7.024 mil
Dielectric between Top layer and 2nd layer relative permittivity (Er): 3.8

minimum finished hole size  : 200 um
minimum spacing             : 100 um
minimum track width         : 100 um

drill diameters             : finished hole

plating finish (both sides) : immersion gold
                              0.08-0.20 um of gold over
                              2.50-5.00 um of nickel

Important Notes
---------------
DRCs must be run on Gerber files before building boards.

Solder mask : dark blue, both sides, halogen free, glossy finish (NOT matte).

Silkscreen : white epoxy ink, halogen free, both sides. No silkscreen on pads.

Electrical test : 100 % netlist.

Boards are to be individually bagged.

Design software used:  KiCad 4.0.2-stable release build

Controlled Impedance
--------------------

  * 50 Ohm coated single ended microstrip (Top layer)
    IT-180A, 7.024 mil, Er = 3.8, metal thickness 0.333+plating
    track width 0.31 mm

Board Stackup
------------
LimeSDR-Sony-F_Paste.gtp
LimeSDR-Sony-F_SilkS.gto
LimeSDR-Sony-F_Mask.gts
LimeSDR-Sony-Front.gtl           (TOP)
LimeSDR-Sony-Inner1_GND.gbr      (L1)
LimeSDR-Sony-Inner2_Signal.gbr   (L2)
LimeSDR-Sony-Inner3_Signal.gbr   (L3)
LimeSDR-Sony-Inner4_Power.gbr    (L4)
LimeSDR-Sony-Back.gbl            (BOT)
LimeSDR-Sony-B_Mask.gbs
LimeSDR-Sony-B_SilkS.gbo
LimeSDR-Sony-B_Paste.gbp

Reports folder
--------------           			                    
LimeSDR-Sony.cmp (component report)
LimeSDR-Sony.drc.rpt (Design Rules Check Report)
LimeSDR_Sony.erc
LimeSDR-Sony.net(netlist)
LimeSDR-Sony-drl.rpt (Drill Size Table Report)

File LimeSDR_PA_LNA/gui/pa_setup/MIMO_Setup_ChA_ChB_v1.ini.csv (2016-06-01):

name | pa_vd | dac_a | eb_a_in | tp_a_in | ssc2_a_in | ssc1_a_in | eb_a_mid | tp_a_mid | ssc2_a_mid | ssc1_a_mid | eb_a_out | tp_a_out | ssc2_a_out | ssc1_a_out | dac_b | eb_b_in | tp_b_in | ssc2_b_in | ssc1_b_in | eb_b_mid | tp_b_mid | ssc2_b_mid | ssc1_b_mid | eb_b_out | tp_b_out | ssc2_b_out | ssc1_b_out
ChA&B_0.3GHz | 5V | 3.02 V | 1 | 1 | 0 | 31 | 0 | 0 | 0 | 25 | 0 | 0 | 0 | 31 | 2.41 V | 1 | 1 | 0 | 31 | 0 | 0 | 0 | 31 | 0 | 0 | 0 | 31
ChA&B_0.5GHz | 5V | 2.68 V | 1 | 1 | 0 | 31 | 0 | 0 | 0 | 25 | 0 | 0 | 0 | 31 | 3.29 V | 1 | 1 | 0 | 31 | 0 | 0 | 0 | 31 | 0 | 0 | 0 | 31
ChA&B_0.8GHz | 5V | 3.12 V | 0 | 0 | 3 | 10 | 0 | 0 | 0 | 8 | 0 | 0 | 0 | 31 | 3.29 V | 0 | 0 | 0 | 10 | 0 | 0 | 0 | 31 | 0 | 0 | 0 | 31
ChA&B_1.0GHz | 5V | 2.68 V | 0 | 0 | 0 | 26 | 0 | 0 | 3 | 0 | 0 | 0 | 0 | 24 | 3.29 V | 0 | 0 | 0 | 31 | 0 | 0 | 0 | 14 | 0 | 1 | 0 | 31
ChA&B_1.5GHz | 5V | 2.54 V | 0 | 0 | 14 | 31 | 1 | 0 | 0 | 0 | 1 | 0 | 0 | 31 | 2.93 V | 0 | 0 | 0 | 31 | 0 | 0 | 6 | 14 | 1 | 1 | 0 | 31
ChA&B_1.8GHz | 5V | 2.87 V | 0 | 0 | 3 | 15 | 1 | 0 | 0 | 0 | 1 | 1 | 0 | 18 | 3.08 V | 0 | 0 | 0 | 31 | 1 | 0 | 0 | 0 | 1 | 1 | 0 | 31
ChA&B_2.1GHz | 5V | 2.75 V | 0 | 0 | 0 | 31 | 1 | 0 | 0 | 0 | 1 | 1 | 0 | 16 | 2.44 V | 0 | 0 | 0 | 31 | 1 | 0 | 0 | 0 | 1 | 1 | 0 | 31
ChA&B_2.5GHz | 5V | 2.99 V | 0 | 0 | 0 | 31 | 0 | 0 | 15 | 31 | 0 | 0 | 0 | 31 | 3.03 V | 0 | 0 | 1 | 31 | 1 | 0 | 8 | 31 | 0 | 0 | 0 | 31
ChA&B_2.7GHz | 5V | 3.26 V | 0 | 0 | 0 | 31 | 1 | 0 | 15 | 31 | 0 | 0 | 0 | 31 | 3.03 V | 0 | 0 | 1 | 31 | 1 | 0 | 8 | 31 | 0 | 0 | 0 | 31
ChA&B_3.0GHz | 5V | 2.60 V | 0 | 0 | 0 | 31 | 1 | 0 | 15 | 31 | 0 | 0 | 0 | 31 | 2.77 V | 0 | 0 | 1 | 31 | 1 | 0 | 8 | 31 | 0 | 0 | 0 | 31
ChA&B_3.3GHz | 5V | 3.29 V | 0 | 0 | 0 | 31 | 1 | 0 | 15 | 31 | 0 | 0 | 0 | 31 | 3.20 V | 0 | 0 | 1 | 31 | 1 | 0 | 8 | 31 | 0 | 0 | 0 | 31
ChA&B_3.5GHz | 5V | 2.73 V | 0 | 0 | 0 | 31 | 1 | 0 | 15 | 31 | 0 | 0 | 0 | 31 | 3.20 V | 0 | 0 | 1 | 31 | 1 | 0 | 8 | 31 | 0 | 0 | 0 | 31
ChA&B_3.8GHz | 5V | 2.73 V | 0 | 0 | 0 | 31 | 1 | 0 | 15 | 31 | 0 | 0 | 0 | 31 | 3.20 V | 0 | 0 | 1 | 31 | 1 | 0 | 8 | 31 | 0 | 0 | 0 | 31

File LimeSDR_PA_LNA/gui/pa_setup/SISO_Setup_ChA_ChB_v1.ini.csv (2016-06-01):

name | pa_vd | dac_a | eb_a_in | tp_a_in | ssc2_a_in | ssc1_a_in | eb_a_mid | tp_a_mid | ssc2_a_mid | ssc1_a_mid | eb_a_out | tp_a_out | ssc2_a_out | ssc1_a_out | dac_b | eb_b_in | tp_b_in | ssc2_b_in | ssc1_b_in | eb_b_mid | tp_b_mid | ssc2_b_mid | ssc1_b_mid | eb_b_out | tp_b_out | ssc2_b_out | ssc1_b_out
ChA_0.3GHz | 5V | 2.82 V | 1 | 1 | 0 | 31 | 0 | 0 | 0 | 25 | 0 | 0 | 0 | 31 | 0.00 V | 0 | 0 | 0 | 0 | 0 | 0 | 0 | 0 | 0 | 0 | 0 | 0
ChA_0.5GHz | 5V | 2.22 V | 1 | 1 | 0 | 31 | 0 | 0 | 0 | 25 | 0 | 0 | 0 | 31 | 0.00 V | 0 | 0 | 0 | 0 | 0 | 0 | 0 | 0 | 0 | 0 | 0 | 0
ChA_0.8GHz | 5V | 2.22 V | 0 | 0 | 3 | 10 | 0 | 0 | 0 | 8 | 0 | 0 | 0 | 31 | 0.00 V | 0 | 0 | 0 | 0 | 0 | 0 | 0 | 0 | 0 | 0 | 0 | 0
ChA_1.0GHz | 5V | 2.22 V | 0 | 0 | 0 | 26 | 0 | 0 | 3 | 0 | 0 | 0 | 0 | 24 | 0.00 V | 0 | 0 | 0 | 0 | 0 | 0 | 0 | 0 | 0 | 0 | 0 | 0
ChA_1.5GHz | 5V | 2.22 V | 0 | 0 | 14 | 31 | 1 | 0 | 0 | 0 | 1 | 0 | 0 | 31 | 0.00 V | 0 | 0 | 0 | 0 | 0 | 0 | 0 | 0 | 0 | 0 | 0 | 0
ChA_1.8GHz | 5V | 2.14 V | 0 | 0 | 3 | 15 | 1 | 0 | 0 | 0 | 1 | 1 | 0 | 18 | 0.00 V | 0 | 0 | 0 | 0 | 0 | 0 | 0 | 0 | 0 | 0 | 0 | 0
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

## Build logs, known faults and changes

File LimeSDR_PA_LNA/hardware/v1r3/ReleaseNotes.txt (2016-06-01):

LimeSDR-Sony Chnages:
LimeSDR-Sony_Database v1.rar (Manufactured)
			      - Initial 
LimeSDR-Sony_Database v2.rar (Not manufactured)
			     - Added PDF with lauout
                             - In KiCad schematic library correted components details
                             - Same BOM is generated with corret field values on some of the components, corrected BOM file revision is v1r2
                             - New 'LimeSDR_Sony.net' and 'LimeSDR_Sony-pick_place_v1.pos' files is generated according to corrected BOM
			     - In 'PCB Manufacturing info' folder in 'ReadMe' file Board Stackup corrected line: 'LimeSDR-Sony-Inner2_Signal.gbr (L3)' to 'LimeSDR-Sony-Inner3_Signal.gbr (L3)'
                             - In 'PCB Manufacturing info' folder added stackup file 'LimeSDR v1r1 Stack-up by Fast Print.pdf'   
                             - Added file 'LimeSDR-Sony Changes.txt'  
LimeSDR-Sony_Database v3.rar New to update Schematics and Layout:
                             - Corrected J3 footprint
                             - Added second tactile button for MCU HWB line and place near RST button
                             - Added 22R resistors to DATA- and DATA+ lines  
			     - Remove R42 from +5V and added instead of FB1.
                             - C106 value changed to 10nF
                             - Marked connector J3 (UART) pins (RX, TX) for clarity reason
                             - SMA Female conenctor part number is changed to fit board thiknes
			     - XO1 is changed to XT1 reference name.    
			     - Mark RF directions (arrows) on each board for clarity
			     - Updated all related database files: pdf, gerbs, repot files, pick and place, BOM, Net

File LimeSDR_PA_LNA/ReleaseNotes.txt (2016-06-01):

Release notes:
==============

1. Initial release.

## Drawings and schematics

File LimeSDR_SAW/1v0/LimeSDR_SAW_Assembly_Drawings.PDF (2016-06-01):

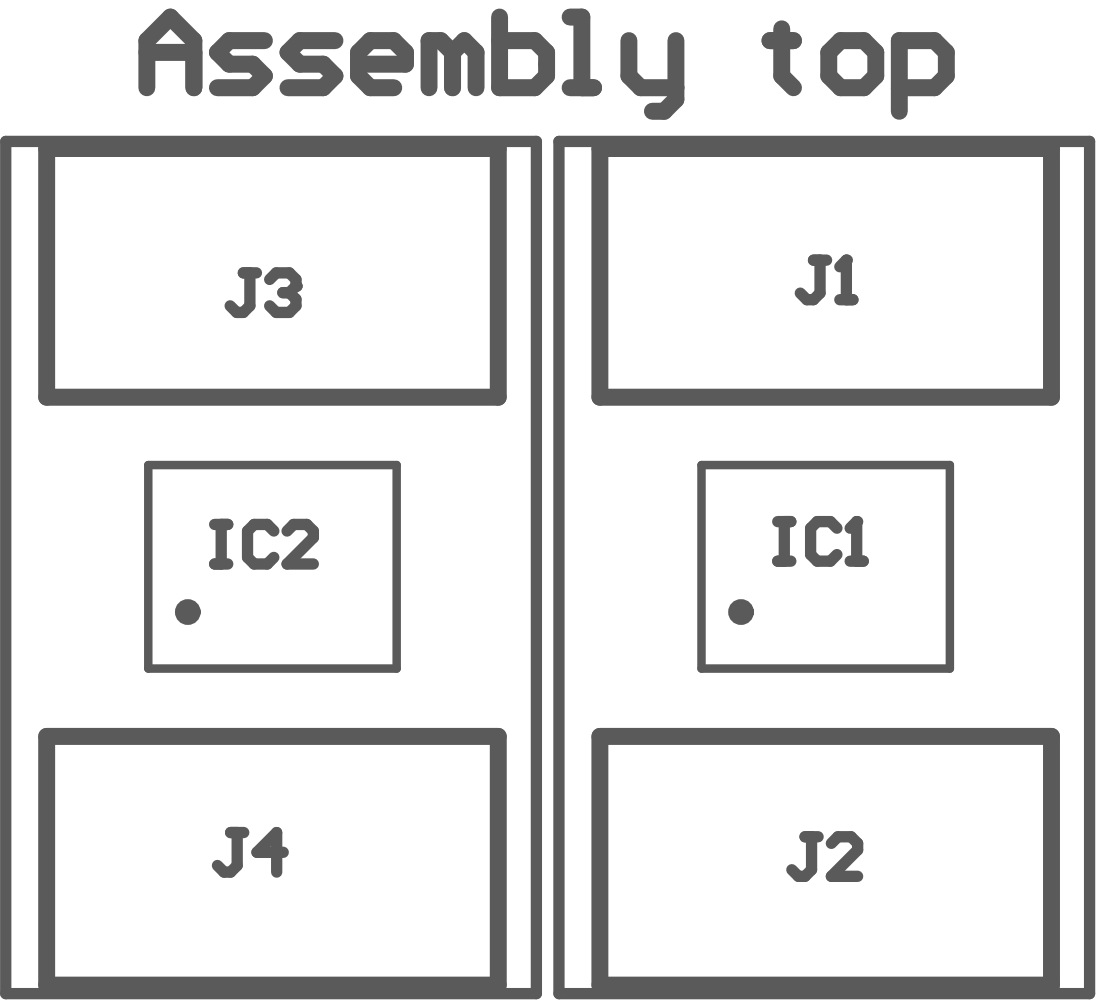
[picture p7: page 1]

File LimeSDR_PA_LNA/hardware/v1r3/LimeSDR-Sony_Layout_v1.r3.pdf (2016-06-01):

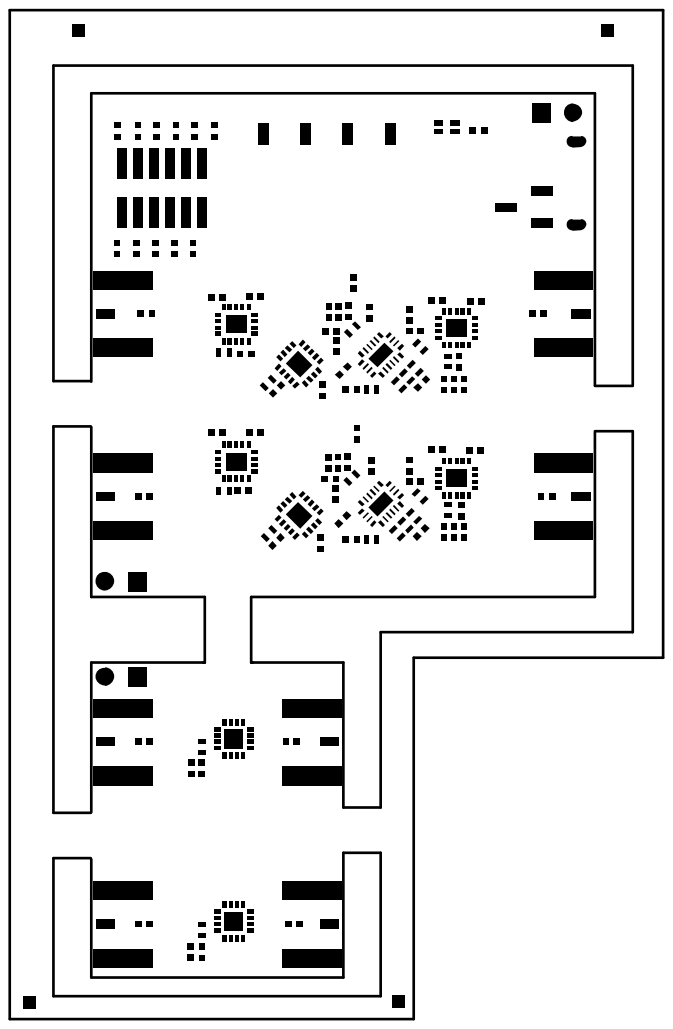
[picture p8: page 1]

LimeSDR_Sony-F.Paste.gtp Scale=1.00 Mon May 23 22:30:30 2016

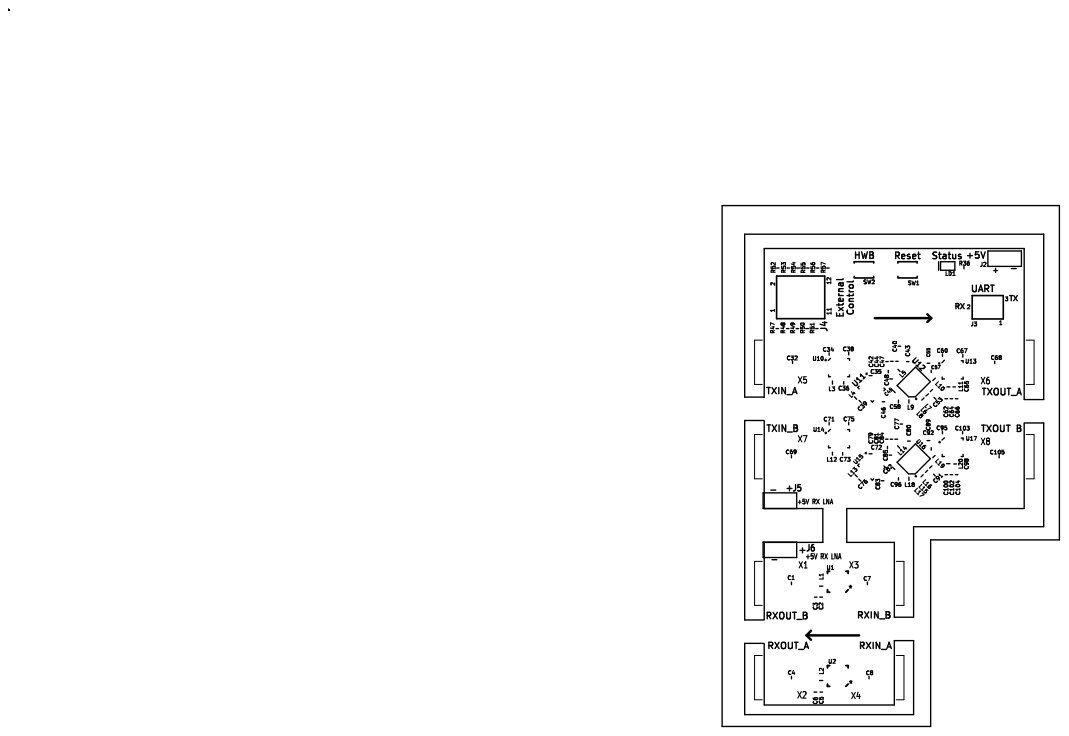
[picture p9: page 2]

LimeSDR_Sony-F.SilkS.gto Scale=1.00 Mon May 23 22:30:30 2016

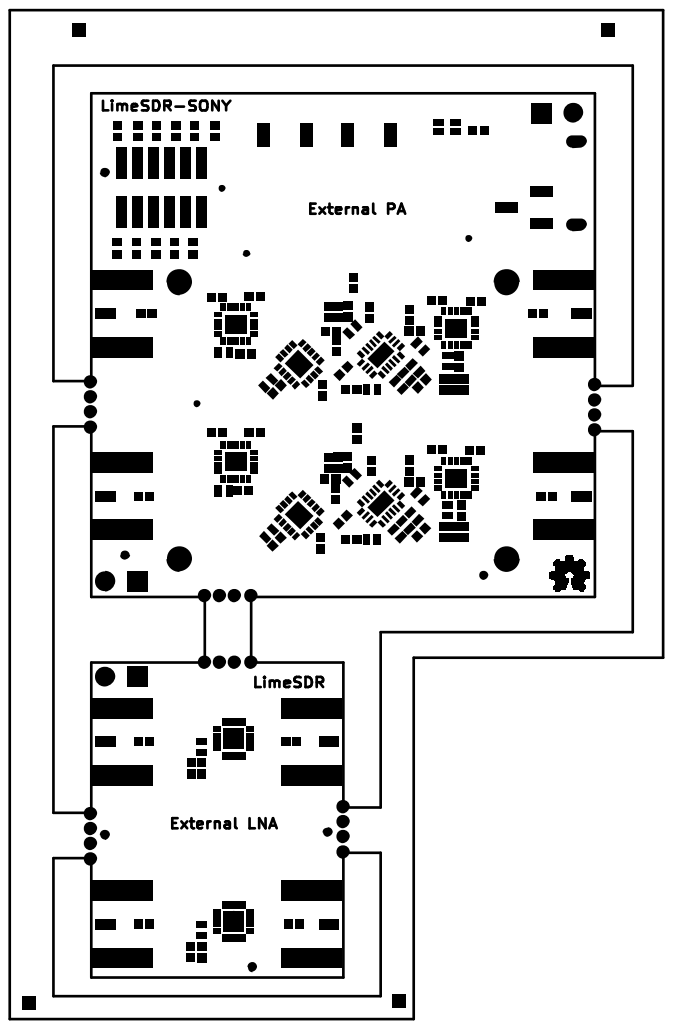
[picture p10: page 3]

LimeSDR_Sony-F.Mask.gts Scale=1.00 Mon May 23 22:30:30 2016

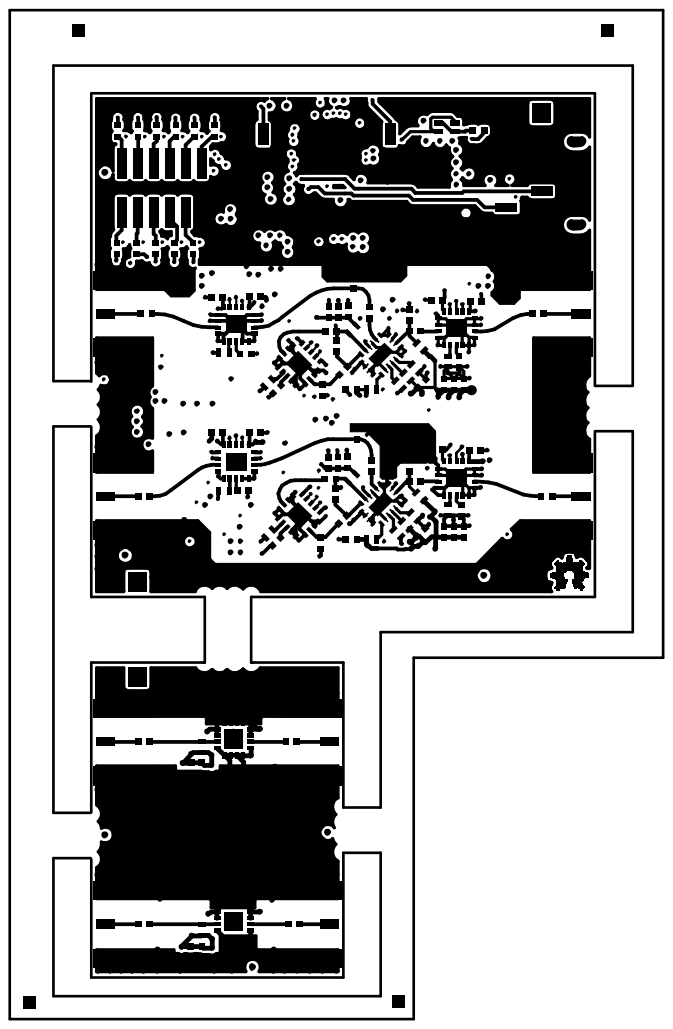
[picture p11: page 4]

LimeSDR_Sony-Front.gtl Scale=1.00 Mon May 23 22:30:30 2016

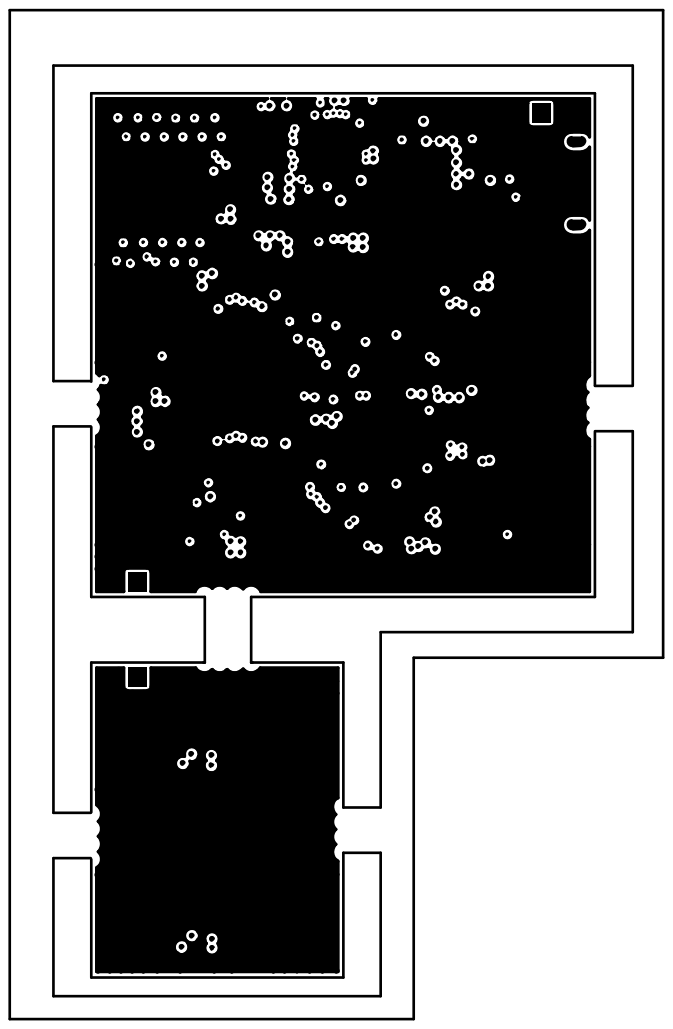
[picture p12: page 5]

LimeSDR_Sony-Inner1_GND.g2 Scale=1.00 Mon May 23 22:30:30 2016

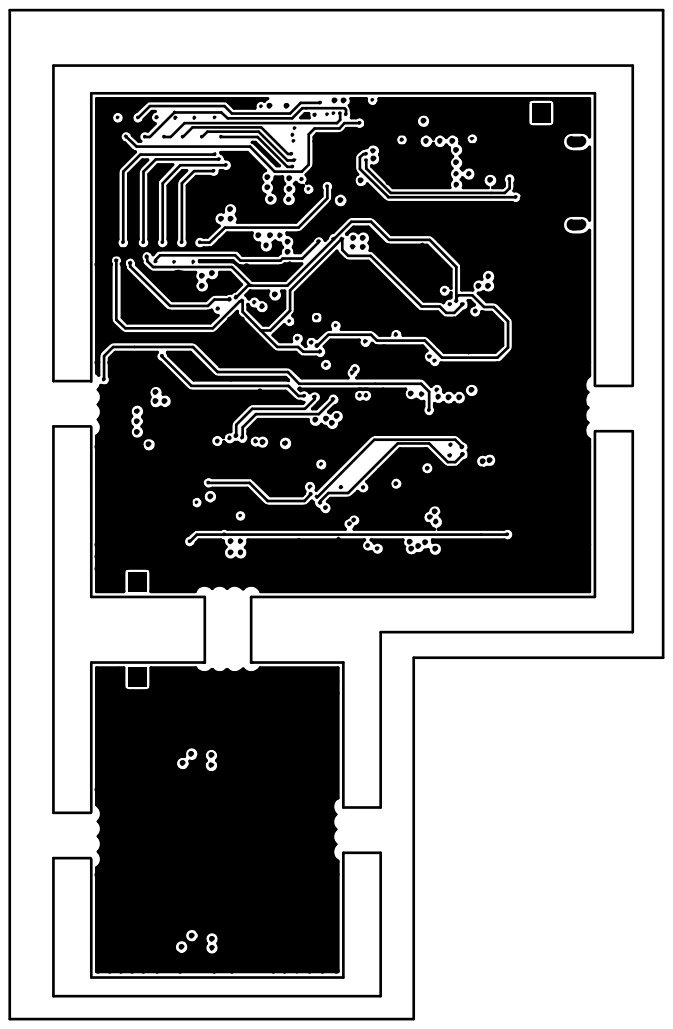
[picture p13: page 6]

LimeSDR_Sony-Inner2_Signal.g3 Scale=1.00 Mon May 23 22:30:30 2016

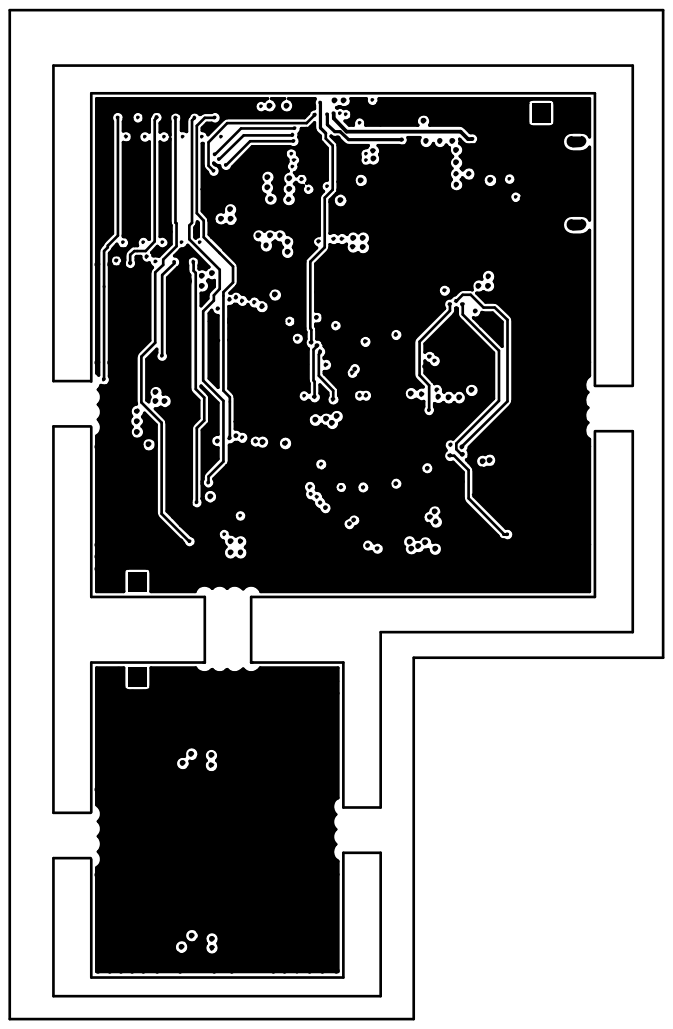
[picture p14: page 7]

LimeSDR_Sony-Inner3_Signal.g4 Scale=1.00 Mon May 23 22:30:30 2016

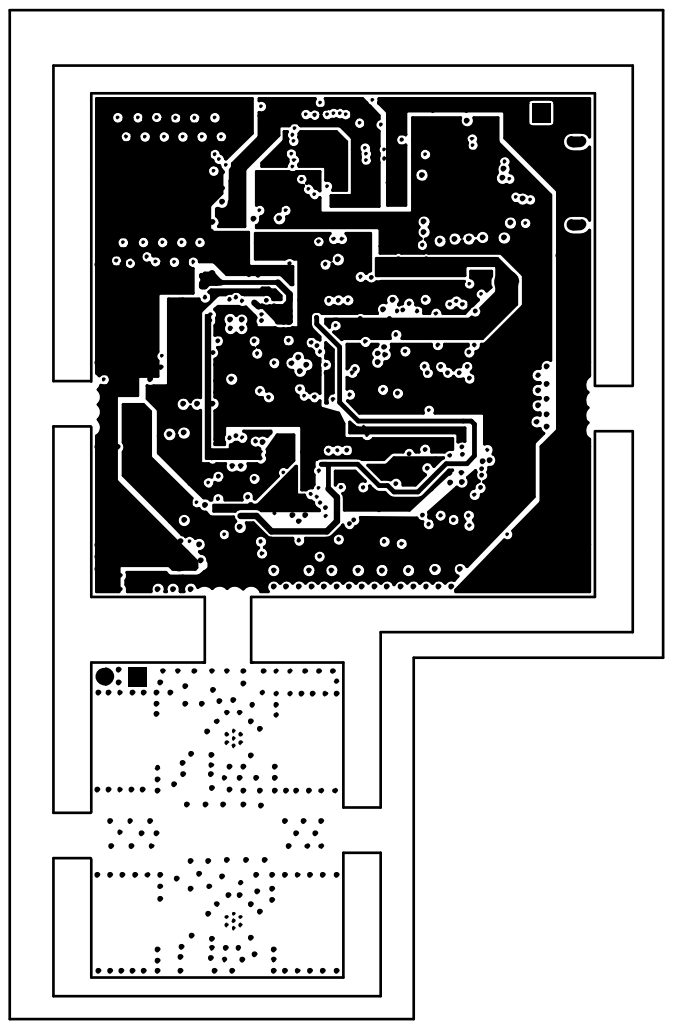
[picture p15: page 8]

LimeSDR_Sony-Inner4_Power.g5 Scale=1.00 Mon May 23 22:30:30 2016

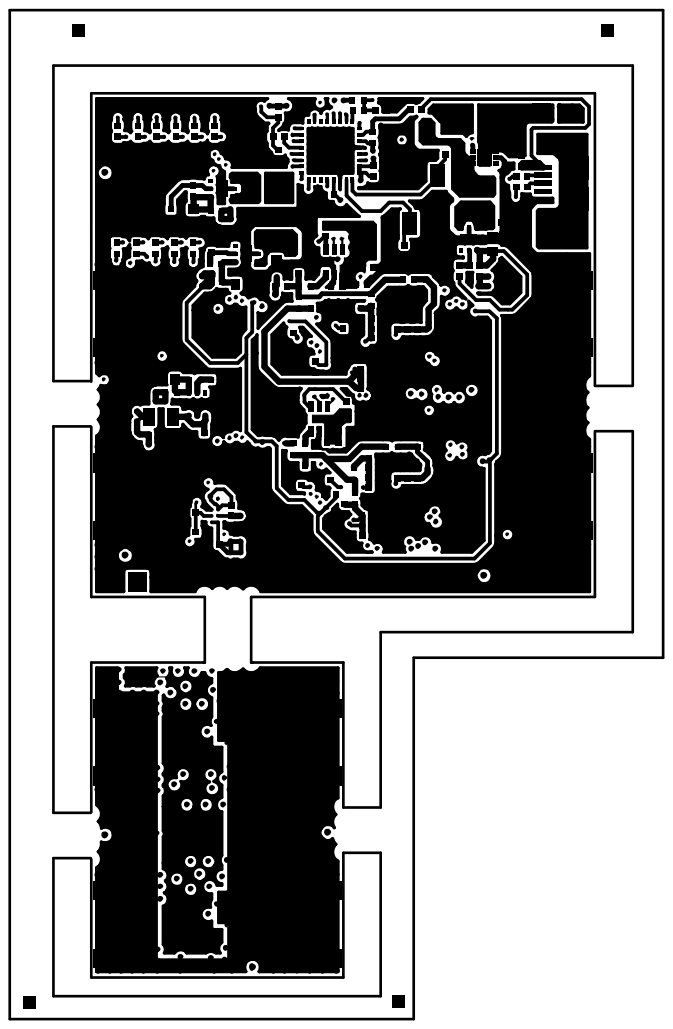
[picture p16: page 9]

LimeSDR_Sony-Back.gbl Scale=1.00 Mon May 23 22:30:30 2016

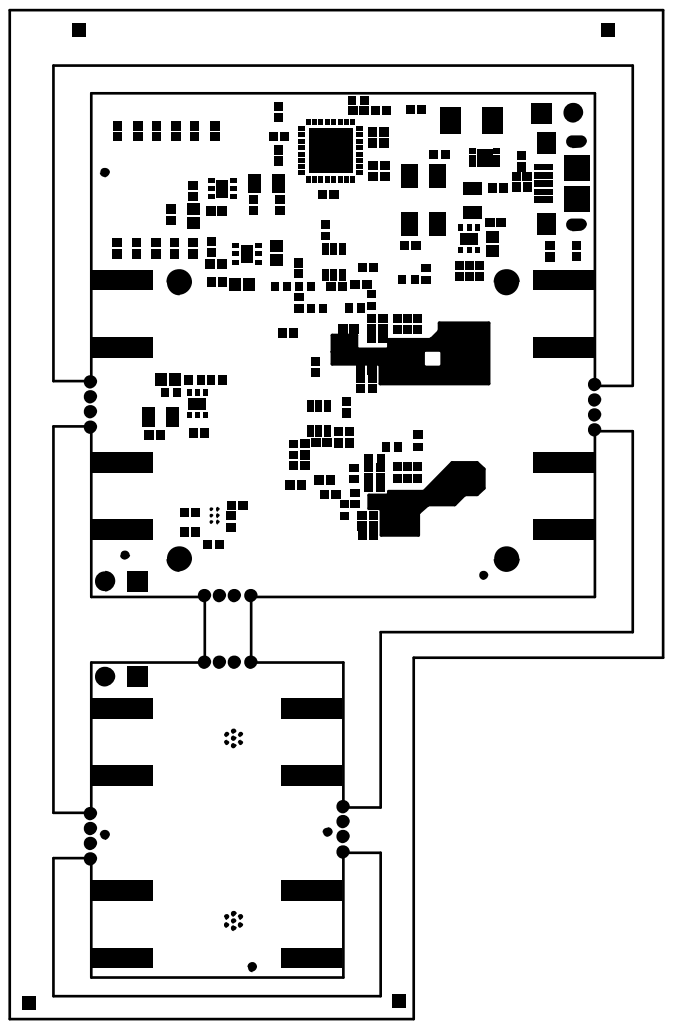
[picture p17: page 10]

LimeSDR_Sony-B.Mask.gbs Scale=1.00 Mon May 23 22:30:30 2016

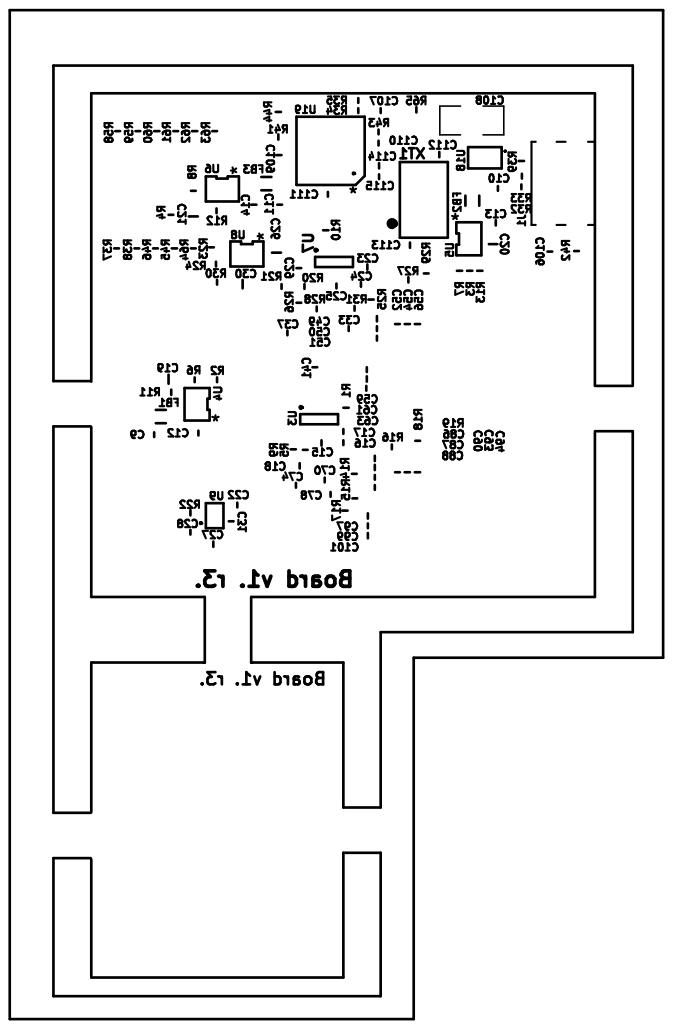
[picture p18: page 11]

LimeSDR_Sony-B.SilkS.gbo Scale=1.00 Mon May 23 22:30:30 2016


LimeSDR_Sony-B.Paste.gbp Scale=1.00 Mon May 23 22:30:30 2016


LimeSDR_Sony-Edge.Cuts.gm1 Scale=1.00 Mon May 23 22:30:30 2016


LimeSDR_Sony.drl Scale=1.00 Mon May 23 22:30:30 2016


LimeSDR_Sony-NPTH.drl Scale=1.00 Mon May 23 22:30:30 2016


LimeSDR_Sony-Dwgs.User.gbr Scale=1.00 Mon May 23 22:30:30 2016


LimeSDR_Sony-Cmts.User.gbr Scale=1.00 Mon May 23 22:30:30 2016







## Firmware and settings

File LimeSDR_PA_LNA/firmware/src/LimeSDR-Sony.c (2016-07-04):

/*
             LUFA Library
     Copyright (C) Dean Camera, 2009, 2013 Lime Microsystems.
              
  dean [at] fourwalledcubicle [dot] com
      www.fourwalledcubicle.com
*/

/*
  Copyright 2009  Dean Camera (dean [at] fourwalledcubicle [dot] com)

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
  Lime Microsystems modified this source. Left the main part of 
  the code which implements virtual COM port functionality. 
  Added additional functionality for LMS board controlling.
*/
#include "LimeSDR-Sony.h"
#include "global.h"
#include "LMS64C_protocol.h"

/* Scheduler Task List */
TASK_LIST
{
	{ .Task = USB_USBTask          , .TaskStatus = TASK_STOP },
	{ .Task = CDC_Task             , .TaskStatus = TASK_STOP },
	{ .Task = Main_Task            , .TaskStatus = TASK_STOP },
};

/* Globals: */
/** Contains the current baud rate and other settings of the virtual serial port.
 *
 *  These values are set by the host via a class-specific request, and the physical USART should be reconfigured to match the
 *  new settings each time they are changed by the host.
 */
CDC_Line_Coding_t LineCoding = { .BaudRateBPS = 9600,
                                 .CharFormat  = OneStopBit,
                                 .ParityType  = Parity_None,
                                 .DataBits    = 8            };

/** Ring (circular) buffer to hold the RX data - data from the host to the attached device on the serial port. */
RingBuff_t Rx_Buffer;

/** Ring (circular) buffer to hold the TX data - data from the attached device on the serial port to the host. */
RingBuff_t Tx_Buffer;

enum {
SPI_ADDR_0x00, SPI_ADDR_0x01, SPI_ADDR_0x02,
SPI_ADDR_0x10,
SPI_ADDR_0x20, SPI_ADDR_0x21, SPI_ADDR_0x22, SPI_ADDR_0x23, SPI_ADDR_0x24, SPI_ADDR_0x25,
SPI_ADDR_0x30, SPI_ADDR_0x31,
SPI_ADDR_ALL};

unsigned int spi_reg[SPI_ADDR_ALL], spi_reg_addr, spi_reg_data;


/* some global variables used throughout */
unsigned char tx_buff[LMS_CTRL_PACKET_SIZE], rx_buff[LMS_CTRL_PACKET_SIZE], count, reg_idx, Exp_board_id;

enum {LED_MODE_OFF, LED_MODE_ON, LED_MODE_WINK, LED_MODE_BLINK1, LED_MODE_BLINK2};

unsigned long int current_portion, last_portion;
unsigned char flash_page_cnt, finish_flash_page, data_cnt, GPIO_states[1] = {0b00000011};//GPIO0 - rst for HPM1000, GPIO1 - SSN for HPM1000
unsigned short flash_page_addr, flash_word, flash_byte;

unsigned char LED_mode = LED_MODE_OFF, LED_timeout; //variables for LED

tLMS_Ctrl_Packet *LMS_Ctrl_Packet_Tx = (tLMS_Ctrl_Packet*)tx_buff;
tLMS_Ctrl_Packet *LMS_Ctrl_Packet_Rx = (tLMS_Ctrl_Packet*)rx_buff;

//prototypes
//void Update_GPIO_outs (void);
void Set_LED_mode (unsigned char mode);
void SPI_write_DAC (unsigned char Byte);
void SPI_write_tuner (unsigned int data);

/** Timer 0 interrupt for periodic tasks
 *  8MHz/64/256 = 488.28125 Hz 
*/
ISR(TIMER0_OVF_vect)
{
	if (LED_mode == LED_MODE_WINK && LED_timeout) 
	{
		LED_timeout--;
		if(LED_timeout==0) 
		{
			LED_mode = LED_MODE_OFF;
			//green
			cbi(PORTB, LED_R);
			sbi(PORTB, LED_G); 
		}
	}
}

/** Main program entry point. This routine configures the hardware required by the application, then
 *  starts the scheduler to run the application tasks.
 */
int main(void)
{
	/* Disable watchdog if enabled by bootloader/fuses */
	MCUSR &= ~(1 << WDRF);
	wdt_disable();

	/* Disable clock division */
	clock_prescale_set(clock_div_1); // with 8MHz crystal, this means CLK=8000000

	/* Hardware Initialization */
	
	//set outputs directions
	// Prepare PortB for SPI - set PB0(^SS), PB1(SCK), PB2(MOSI) as output as well as all other pins except PB3(MISO)
	sbi (DDRB, MCU_SPI_DACA_SS);
	sbi (DDRB, MCU_SPI_SCLK);
	sbi (DDRB, MCU_SPI_MOSI);
	sbi (DDRB, MCU_SPI_MOSI);
	sbi (DDRB, MCU_SPI_DACB_SS);
	sbi (DDRB, LED_R);
	sbi (DDRB, LED_G);
	
	sbi (DDRC, VD_DRIVE_SELECT);
	sbi (DDRC, MCU_TUNERA_OUT_SS);
	sbi (DDRC, MCU_TUNERA_MID_SS);
	sbi (DDRC, MCU_TUNERA_IN_SS);
	
	sbi (DDRD, MCU_TUNERB_IN_SS);
	sbi (DDRD, MCU_TUNERB_MID_SS);
	sbi (DDRD, MCU_TUNERB_OUT_SS);

	//set outputs levels
	sbi (PORTB, MCU_SPI_DACA_SS);
	sbi (PORTB, MCU_SPI_DACB_SS);
	
	cbi (PORTC, MCU_TUNERA_OUT_SS);
	cbi (PORTC, MCU_TUNERA_MID_SS);
	cbi (PORTC, MCU_TUNERA_IN_SS);
	
	cbi (PORTD, MCU_TUNERB_IN_SS);
	cbi (PORTD, MCU_TUNERB_MID_SS);
	cbi (PORTD, MCU_TUNERB_OUT_SS);
	
	
	//spi registers defaults
	spi_reg[SPI_ADDR_0x00] = DEV_TYPE; //DEV_ID 
	spi_reg[SPI_ADDR_0x01] = HW_VER; //HW_VER  
	spi_reg[SPI_ADDR_0x02] = FW_VER; //FW_VER 

	
	spi_reg[SPI_ADDR_0x10] = 0b00000000; //GPIO
	
	spi_reg[SPI_ADDR_0x20] = 0b0000001000000000; //TUNER_A_IN
	spi_reg[SPI_ADDR_0x21] = 0b0000001000000000; //TUNER_A_MID
	spi_reg[SPI_ADDR_0x22] = 0b0000001000000000; //TUNER_A_OUT
	
	spi_reg[SPI_ADDR_0x23] = 0b0000001000000000; //TUNER_B_IN
	spi_reg[SPI_ADDR_0x24] = 0b0000001000000000; //TUNER_B_MID
	spi_reg[SPI_ADDR_0x25] = 0b0000001000000000; //TUNER_B_OUT
	
	spi_reg[SPI_ADDR_0x30] = 0x00; //DAC_A[7:0] (0V)
	spi_reg[SPI_ADDR_0x31] = 0x00; //DAC_B[7:0] (0V)
	
	Set_LED_mode (LED_MODE_WINK);
	
	/* 8-bit Timer0 Initialization */
	TCCR0B = (1 << CS01)|(1 << CS00);  // prescale Timer1 by CLK/64
	TIMSK0 = (1 << TOIE0); //Timer0 Overflow Interrupt Enable
	
	/* Ring buffer Initialization */
	Buffer_Initialize(&Rx_Buffer);
	Buffer_Initialize(&Tx_Buffer);

	/* Initialize Scheduler so that it can be used */
	Scheduler_Init();

	/* Initialize USB Subsystem */
	USB_Init();

	/* Scheduling - routine never returns, so put this last in the main function */
	Scheduler_Start();
}

/** Event handler for the USB_Connect event. This indicates that the device is enumerating via the status LEDs and
 *  starts the library USB task to begin the enumeration and USB management process.
 */
void EVENT_USB_Connect(void)
{
	/* Start USB management task */
	Scheduler_SetTaskMode(USB_USBTask, TASK_RUN);

	/* Indicate USB enumerating */
	//UpdateStatus(Status_USBEnumerating);
}

/** Event handler for the USB_Disconnect event. This stops the USB management and CDC management tasks.
 */
void EVENT_USB_Disconnect(void)
{
	/* Stop running CDC and USB management tasks */
	Scheduler_SetTaskMode(CDC_Task, TASK_STOP);
	Scheduler_SetTaskMode(USB_USBTask, TASK_STOP);
	
	/* Reset Tx and Rx buffers, device disconnected */
	Buffer_Initialize(&Rx_Buffer);
	Buffer_Initialize(&Tx_Buffer);
	
	Set_LED_mode (LED_MODE_WINK);
}

/** Event handler for the USB_ConfigurationChanged event. This is fired when the host set the current configuration
 *  of the USB device after enumeration - the device endpoints are configured and the CDC management task started.
 */
void EVENT_USB_ConfigurationChanged(void)
{
	/* Setup CDC Notification, Rx and Tx Endpoints */
	Endpoint_ConfigureEndpoint(CDC_NOTIFICATION_EPNUM, EP_TYPE_INTERRUPT,
		                       ENDPOINT_DIR_IN, CDC_NOTIFICATION_EPSIZE,
	                           ENDPOINT_BANK_SINGLE);

	Endpoint_ConfigureEndpoint(CDC_TX_EPNUM, EP_TYPE_BULK,
		                       ENDPOINT_DIR_IN, CDC_TXRX_EPSIZE,
	                           ENDPOINT_BANK_SINGLE);

	Endpoint_ConfigureEndpoint(CDC_RX_EPNUM, EP_TYPE_BULK,
		                       ENDPOINT_DIR_OUT, CDC_TXRX_EPSIZE,
	                           ENDPOINT_BANK_SINGLE);

	/* Start CDC task */
	Scheduler_SetTaskMode(CDC_Task, TASK_RUN);
	Scheduler_SetTaskMode(Main_Task, TASK_RUN);
}

/** Event handler for the USB_UnhandledControlPacket event. This is used to catch standard and class specific
 *  control requests that are not handled internally by the USB library (including the CDC control commands,
 *  which are all issued via the control endpoint), so that they can be handled appropriately for the application.
 */
void EVENT_USB_UnhandledControlPacket(void)
{
	uint8_t* LineCodingData = (uint8_t*)&LineCoding;

	/* Process CDC specific control requests */
	switch (USB_ControlRequest.bRequest)
	{
		case REQ_GetLineEncoding:
			if (USB_ControlRequest.bmRequestType == (REQDIR_DEVICETOHOST | REQTYPE_CLASS | REQREC_INTERFACE))
			{	
				/* Acknowledge the SETUP packet, ready for data transfer */
				Endpoint_ClearSETUP();

				/* Write the line coding data to the control endpoint */
				Endpoint_Write_Control_Stream_LE(LineCodingData, sizeof(LineCoding));
				
				/* Finalize the stream transfer to send the last packet or clear the host abort */
				Endpoint_ClearOUT();
			}
			
			break;
		case REQ_SetLineEncoding:
			if (USB_ControlRequest.bmRequestType == (REQDIR_HOSTTODEVICE | REQTYPE_CLASS | REQREC_INTERFACE))
			{
				/* Acknowledge the SETUP packet, ready for data transfer */
				Endpoint_ClearSETUP();

				/* Read the line coding data in from the host into the global struct */
				Endpoint_Read_Control_Stream_LE(LineCodingData, sizeof(LineCoding));

				/* Finalize the stream transfer to clear the last packet from the host */
				Endpoint_ClearIN();
				
				/* Reconfigure the USART with the new settings */
				//Reconfigure_SPI_for_LMS();
			}
	
			break;
		case REQ_SetControlLineState:
			if (USB_ControlRequest.bmRequestType == (REQDIR_HOSTTODEVICE | REQTYPE_CLASS | REQREC_INTERFACE))
			{				
				/* Acknowledge the SETUP packet, ready for data transfer */
				Endpoint_ClearSETUP();
				
				/* NOTE: Here you can read in the line state mask from the host, to get the current state of the output handshake
				         lines. The mask is read in from the wValue parameter in USB_ControlRequest, and can be masked against the
						 CONTROL_LINE_OUT_* masks to determine the RTS and DTR line states using the following code:
				*/

				/* Acknowledge status stage */
				while (!(Endpoint_IsINReady()));
				Endpoint_ClearIN();
			}
	
			break;
	}
	Set_LED_mode (LED_MODE_WINK);
}

/** Task to manage CDC data transmission and reception to and from the host, from and to the physical USART. */
TASK(CDC_Task)
{
	if (USB_IsConnected)
	{
		/* Select the Serial Rx Endpoint */
		Endpoint_SelectEndpoint(CDC_RX_EPNUM);
		
		/* Check to see if a packet has been received from the host */
		if (Endpoint_IsOUTReceived())
		{
			/* Read the bytes in from the endpoint into the buffer while space is available */
			while (Endpoint_BytesInEndpoint() && (BUFF_STATICSIZE - Rx_Buffer.Elements))
			{
				/* Store each character from the endpoint */
				Buffer_StoreElement(&Rx_Buffer, Endpoint_Read_Byte());
			}
			
			/* Check to see if all bytes in the current packet have been read */
			if (!(Endpoint_BytesInEndpoint()))
			{
				/* Clear the endpoint buffer */
				Endpoint_ClearOUT();
			}
		}
		
		/* Select the Serial Tx Endpoint */
		Endpoint_SelectEndpoint(CDC_TX_EPNUM);

		/* Check if the Tx buffer contains anything to be sent to the host */
		if (Tx_Buffer.Elements)
		{
			/* Wait until Serial Tx Endpoint Ready for Read/Write */
			while (!(Endpoint_IsReadWriteAllowed()));
			
			/* Write the bytes from the buffer to the endpoint while space is available */
			while (Tx_Buffer.Elements && (Endpoint_BytesInEndpoint() < CDC_TXRX_EPSIZE))
			{
				/* Write each byte retreived from the buffer to the endpoint */
				Endpoint_Write_Byte(Buffer_GetElement(&Tx_Buffer));
			}
			
			/* Remember if the packet to send completely fills the endpoint */
			bool IsFull = (Endpoint_BytesInEndpoint() == CDC_TXRX_EPSIZE);
			
			/* Send the data */
			Endpoint_ClearIN();

			/* If no more data to send and the last packet filled the endpoint, send an empty packet to release
			 * the buffer on the receiver (otherwise all data will be cached until a non-full packet is received) */
			if (IsFull && !(Tx_Buffer.Elements))
			{
				/* Wait until Serial Tx Endpoint Ready for Read/Write */
				while (!(Endpoint_IsReadWriteAllowed()));

				/* Send an empty packet to terminate the transfer */
				Endpoint_ClearIN();
			}
		}
	}
}


/** After the device is connected to a Host, this task will run periodically,
		even if the device is disconnected.
	Your application code should go here
*/
TASK(Main_Task)
{
	uint8_t block;
	uint16_t cmd_errors;

	if(Rx_Buffer.Elements == LMS_CTRL_PACKET_SIZE) //receveid full packet?
	{
		Set_LED_mode (LED_MODE_ON);
		cmd_errors = 0;
		for (count =0; count <LMS_CTRL_PACKET_SIZE; count++) //get all packets bytes
		{
			rx_buff[count] = Buffer_GetElement(&Rx_Buffer);
		}
		
		memset (tx_buff, 0, sizeof(tx_buff)); //fill whole tx buffer with zeros
		
		LMS_Ctrl_Packet_Tx->Header.Command = LMS_Ctrl_Packet_Rx->Header.Command;
		LMS_Ctrl_Packet_Tx->Header.Data_blocks = LMS_Ctrl_Packet_Rx->Header.Data_blocks;
		LMS_Ctrl_Packet_Tx->Header.Status = STATUS_BUSY_CMD;
		
		switch(LMS_Ctrl_Packet_Rx->Header.Command)
		{
			case CMD_GET_INFO:
				LMS_Ctrl_Packet_Tx->Data_field[0] = FW_VER;
				LMS_Ctrl_Packet_Tx->Data_field[1] = DEV_TYPE;
				LMS_Ctrl_Packet_Tx->Data_field[2] = LMS_PROTOCOL_VER;
				LMS_Ctrl_Packet_Tx->Data_field[3] = HW_VER;
				LMS_Ctrl_Packet_Tx->Data_field[4] = Exp_board_id;
				
				LMS_Ctrl_Packet_Tx->Header.Status = STATUS_COMPLETED_CMD;
				break;
				
			case CMD_BRDSPI16_WR:
				if(Check_many_blocks (4)) break;
				
				for(block = 0; block < LMS_Ctrl_Packet_Rx->Header.Data_blocks; block++)
				{
					cbi(LMS_Ctrl_Packet_Rx->Data_field[0 + (block * 2)], 7);  //clear write bit
					
					spi_reg_addr = ((LMS_Ctrl_Packet_Rx->Data_field[0 + (block * 4)] << 8) | LMS_Ctrl_Packet_Rx->Data_field[1 + (block * 4)]);
					spi_reg_data = ((LMS_Ctrl_Packet_Rx->Data_field[2 + (block * 4)] << 8) | LMS_Ctrl_Packet_Rx->Data_field[3 + (block * 4)]);
					
					switch (spi_reg_addr)
					{
						case 0x10: //GPIO
							spi_reg[SPI_ADDR_0x10] = spi_reg_data;
							
							if (spi_reg[SPI_ADDR_0x10] & 0x01) sbi(PORTC, VD_DRIVE_SELECT);
							else  cbi(PORTC, VD_DRIVE_SELECT);
							
							break;
							
						case 0x20: //TUNER_A_IN control
							spi_reg[SPI_ADDR_0x20] = spi_reg_data;
						
							cbi(PORTB, MCU_SPI_SCLK); //set Clock low
				
							sbi(PORTC, MCU_TUNERA_IN_SS); //select slave
							SPI_write_tuner ((1 << 1) | ((spi_reg[SPI_ADDR_0x20] & 0x7FF) << 2)); //Mode = Active, F1 - F11, endian corrected in function
							cbi(PORTC, MCU_TUNERA_IN_SS); //deselect slave
				
							break;
							
						case 0x21: //TUNER_A_MID control
							spi_reg[SPI_ADDR_0x21] = spi_reg_data;
							
							cbi(PORTB, MCU_SPI_SCLK); //set Clock low
				
							sbi(PORTC, MCU_TUNERA_MID_SS); //select slave
							SPI_write_tuner ((1 << 1) | ((spi_reg[SPI_ADDR_0x21] & 0x7FF) << 2)); //Mode = Active, F1 - F11, endian corrected in function
							cbi(PORTC, MCU_TUNERA_MID_SS); //deselect slave
							
							break;
							
						case 0x22: //TUNER_A_OUT control
							spi_reg[SPI_ADDR_0x22] = spi_reg_data;
							
							cbi(PORTB, MCU_SPI_SCLK); //set Clock low
				
							sbi(PORTC, MCU_TUNERA_OUT_SS); //select slave
							SPI_write_tuner ((1 << 1) | ((spi_reg[SPI_ADDR_0x22] & 0x7FF) << 2)); //Mode = Active, F1 - F11, endian corrected in function
							cbi(PORTC, MCU_TUNERA_OUT_SS); //deselect slave
							break;
							
						case 0x23: //TUNER_B_IN control
							spi_reg[SPI_ADDR_0x23] = spi_reg_data;
							
							cbi(PORTB, MCU_SPI_SCLK); //set Clock low
				
							sbi(PORTD, MCU_TUNERB_IN_SS); //select slave
							SPI_write_tuner ((1 << 1) | ((spi_reg[SPI_ADDR_0x23] & 0x7FF) << 2)); //Mode = Active, F1 - F11, endian corrected in function
							cbi(PORTD, MCU_TUNERB_IN_SS); //deselect slave
							break;
							
						case 0x24: //TUNER_B_MID control
							spi_reg[SPI_ADDR_0x24] = spi_reg_data;
							
							cbi(PORTB, MCU_SPI_SCLK); //set Clock low
				
							sbi(PORTD, MCU_TUNERB_MID_SS); //select slave
							SPI_write_tuner ((1 << 1) | ((spi_reg[SPI_ADDR_0x24] & 0x7FF) << 2)); //Mode = Active, F1 - F11, endian corrected in function
							cbi(PORTD, MCU_TUNERB_MID_SS); //deselect slave
							break;
							
						case 0x25: //TUNER_B_OUT control
							spi_reg[SPI_ADDR_0x25] = spi_reg_data;
							
							cbi(PORTB, MCU_SPI_SCLK); //set Clock low
				
							sbi(PORTD, MCU_TUNERB_OUT_SS); //select slave
							SPI_write_tuner ((1 << 1) | ((spi_reg[SPI_ADDR_0x25] & 0x7FF) << 2)); //Mode = Active, F1 - F11, endian corrected in function
							cbi(PORTD, MCU_TUNERB_OUT_SS); //deselect slave
							break;
							
						case 0x30: //DAC_A control
							spi_reg[SPI_ADDR_0x30] = spi_reg_data;
							
							sbi(PORTB, MCU_SPI_SCLK); //set Clock high
							
							cbi(PORTB, MCU_SPI_DACA_SS); //select slave
							SPI_write_DAC ((unsigned char)spi_reg[SPI_ADDR_0x30] >> 2);  //POWER-DOWN MODE = NORMAL OPERATION (MSB bits = 00) + MSB data
							SPI_write_DAC ((unsigned char)spi_reg[SPI_ADDR_0x30] << 6); //LSB data
							sbi(PORTB, MCU_SPI_DACA_SS); //deselect slave
							
							break;
							
						case 0x31: //DAC_B control
							spi_reg[SPI_ADDR_0x31] = spi_reg_data;
							
							sbi(PORTB, MCU_SPI_SCLK); //set Clock high
							
							cbi(PORTB, MCU_SPI_DACB_SS); //select slave
							SPI_write_DAC ((unsigned char)spi_reg[SPI_ADDR_0x31] >> 2);  //POWER-DOWN MODE = NORMAL OPERATION (MSB bits = 00) + MSB data
							SPI_write_DAC ((unsigned char)spi_reg[SPI_ADDR_0x31] << 6); //LSB data
							sbi(PORTB, MCU_SPI_DACB_SS); //deselect slave
							
							break;
							
						default:
							cmd_errors++;
							break;
					}
				}
				
				if(cmd_errors) LMS_Ctrl_Packet_Tx->Header.Status = STATUS_ERROR_CMD;
 	 			else LMS_Ctrl_Packet_Tx->Header.Status = STATUS_COMPLETED_CMD;
				break;
				
			case CMD_BRDSPI16_RD:
				if(Check_many_blocks (4)) break;
				
				for(block = 0; block < LMS_Ctrl_Packet_Rx->Header.Data_blocks; block++)
				{
					cbi(LMS_Ctrl_Packet_Rx->Data_field[0 + (block * 2)], 7);  //clear write bit
					
					spi_reg_addr = ((LMS_Ctrl_Packet_Rx->Data_field[0 + (block * 4)] << 8) | LMS_Ctrl_Packet_Rx->Data_field[1 + (block * 4)]);
					spi_reg_data = ((LMS_Ctrl_Packet_Rx->Data_field[2 + (block * 4)] << 8) | LMS_Ctrl_Packet_Rx->Data_field[3 + (block * 4)]);
					
					switch (spi_reg_addr)
					{
						case 0x00: //Device ID
							spi_reg_data = spi_reg[SPI_ADDR_0x00];
							break;

						case 0x01: //Hardware version
							spi_reg_data = spi_reg[SPI_ADDR_0x01];
							break;
						
						case 0x02: //Firmware version
							spi_reg_data = spi_reg[SPI_ADDR_0x02];
							break;
						
						case 0x10: //GPIO
							spi_reg_data = spi_reg[SPI_ADDR_0x10];
							break;
							
						case 0x20: //TUNER_A_IN control
							spi_reg_data = spi_reg[SPI_ADDR_0x20];
							break;
							
						case 0x21: //TUNER_A_MID control
							spi_reg_data = spi_reg[SPI_ADDR_0x21];
							break;
							
						case 0x22: //TUNER_A_OUT control
							spi_reg_data = spi_reg[SPI_ADDR_0x22];
							break;
							
						case 0x23: //TUNER_B_IN control
							spi_reg_data = spi_reg[SPI_ADDR_0x23];
							break;
							
						case 0x24: //TUNER_B_MID control
							spi_reg_data = spi_reg[SPI_ADDR_0x24];
							break;
							
						case 0x25: //TUNER_B_OUT control
							spi_reg_data = spi_reg[SPI_ADDR_0x25];
							break;
							
						case 0x30: //DAC_A control
							spi_reg_data = spi_reg[SPI_ADDR_0x30];
							break;
							
						case 0x31: //DAC_B control
							spi_reg_data = spi_reg[SPI_ADDR_0x31];
							break;
						
						default: //error
							spi_reg_data = 0xEEEE;
							cmd_errors++;
							break;
					}
					

					LMS_Ctrl_Packet_Tx->Data_field[2 + (block * 4)] = (spi_reg_data >> 8) & 0xFF; //reg data MSB
					LMS_Ctrl_Packet_Tx->Data_field[3 + (block * 4)] = spi_reg_data & 0xFF; //reg data LSB
				}

				if(cmd_errors) LMS_Ctrl_Packet_Tx->Header.Status = STATUS_ERROR_CMD;
 	 			else LMS_Ctrl_Packet_Tx->Header.Status = STATUS_COMPLETED_CMD;
				break;				
				
			default:
				
				LMS_Ctrl_Packet_Tx->Header.Status = STATUS_UNKNOWN_CMD;
				break;
		}
		
		//send prepared tx buffer to PC
		for (count =  0; count < LMS_CTRL_PACKET_SIZE; count++)
		{
			Buffer_StoreElement(&Tx_Buffer, tx_buff[count]);
		}
		Set_LED_mode (LED_MODE_WINK);
	}
}


/**	Inaccurate software delay function to get required delay in microseconds. */
void Delay_us (unsigned int cycles)
{
	while (cycles--)
	{
		asm volatile("nop"); 
		asm volatile("nop"); 
		asm volatile("nop");
	}	
}

/**	This function checks if all blocks could fit in data field.
*	If blocks will not fit, function returns TRUE. */
unsigned char Check_many_blocks (unsigned char block_size)
{
	if (LMS_Ctrl_Packet_Rx->Header.Data_blocks > (sizeof(LMS_Ctrl_Packet_Tx->Data_field)/block_size)) 
	{
		LMS_Ctrl_Packet_Tx->Header.Status = STATUS_BLOCKS_ERROR_CMD;
		return TRUE;
	}
	else return FALSE;
}

/**	Function to control LED mode. */
void Set_LED_mode (unsigned char mode)
{
	LED_mode = mode;//save new LED mode
	
	switch (LED_mode)
	{
		case LED_MODE_OFF: 
			//green
			cbi(PORTB, LED_R);
			sbi(PORTB, LED_G); 
			break;
			
		case LED_MODE_ON:
			//red
			sbi(PORTB, LED_R);
			cbi(PORTB, LED_G);
			break;
		
		case LED_MODE_WINK:
			//red
			sbi(PORTB, LED_R);
			cbi(PORTB, LED_G);
			LED_timeout = 100; //set LED timeout
			break;
	}
}

void SPI_write_DAC (unsigned char Byte)
{
	unsigned char i;
	
	for(i = 8; i > 0; i--) //LSB First
	{
		if((Byte >> (i-1))&1)	//if current bit is 1
		{
			sbi(PORTB, MCU_SPI_MOSI); //Set Output High
		}
		else
		{
			cbi(PORTB, MCU_SPI_MOSI); //Set Output Low
		}	
		
		cbi(PORTB, MCU_SPI_SCLK);	//set Clock low
		sbi(PORTB, MCU_SPI_SCLK);	//set Clock high
	}
}
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

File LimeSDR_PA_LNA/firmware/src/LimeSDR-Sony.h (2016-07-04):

/*
             LUFA Library
     Copyright (C) Dean Camera, 2009, 2013 Lime Microsystems.
              
  dean [at] fourwalledcubicle [dot] com
      www.fourwalledcubicle.com
*/

/*
  Copyright 2009  Dean Camera (dean [at] fourwalledcubicle [dot] com)

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
  The author disclaim all warranties with regard to this
  software, including all implied warranties of merchantability
  and fitness.  In no event shall the author be liable for any
  special, indirect or consequential damages or any damages
  whatsoever resulting from loss of use, data or profits, whether
  in an action of contract, negligence or other tortious action,
  arising out of or in connection with the use or performance of
  this software.
*/

#ifndef _LIMESDR-SONY_H_
#define _LIMESDR-SONY_H_

	/* Includes: */
	#include <avr/io.h>
	#include <avr/wdt.h>
	#include <avr/interrupt.h>
	#include <avr/power.h>

	#include "Descriptors.h"

	#include "global.h"

	#include "libs/ringbuff/RingBuff.h"

	#include <LUFA/Version.h>								// Library Version Information
	#include <LUFA/Drivers/USB/USB.h>				// USB Functionality
	#include <LUFA/Drivers/Peripheral/SPI.h>		// LEDs driver
	#include <LUFA/Scheduler/Scheduler.h>			// Simple scheduler for task management

	//get info
	#define FW_VER			2
	#define DEV_TYPE		LMS_DEV_LIMESDR_SONY_PA
	#define HW_VER			0

	//ports pins

	//PORTB
	#define MCU_SPI_DACA_SS		PB0 //AD5601
	#define MCU_SPI_SCLK		PB1
	#define MCU_SPI_MOSI		PB2
	#define MCU_SPI_DACB_SS		PB4 //AD5601
	#define LED_R				PB6
	#define LED_G				PB7

	//PORTC
	#define VD_DRIVE_SELECT		PC2
	#define MCU_TUNERA_OUT_SS	PC5 //CXM3624UR
	#define MCU_TUNERA_MID_SS	PC6 //CXM3624UR
	#define MCU_TUNERA_IN_SS	PC7 //CXM3624UR

	//PORTD
	#define UART_RX	PD2
	#define UART_TX	PD3
	#define MCU_TUNERB_IN_SS	PD4 //CXM3624UR
	#define MCU_TUNERB_MID_SS	PD5 //CXM3624UR
	#define MCU_TUNERB_OUT_SS	PD6 //CXM3624UR

	/* Macros: */
		/** CDC Class specific request to get the current virtual serial port configuration settings. */
		#define REQ_GetLineEncoding          0x21

		/** CDC Class specific request to set the current virtual serial port configuration settings. */
		#define REQ_SetLineEncoding          0x20

		/** CDC Class specific request to set the current virtual serial port handshake line states. */
		#define REQ_SetControlLineState      0x22
		
		/** Notification type constant for a change in the virtual serial port handshake line states, for
		 *  use with a USB_Notification_Header_t notification structure when sent to the host via the CDC 
		 *  notification endpoint.
		 */
		#define NOTIF_SerialState            0x20

		/** Mask for the DTR handshake line for use with the REQ_SetControlLineState class specific request
		 *  from the host, to indicate that the DTR line state should be high.
		 */
		#define CONTROL_LINE_OUT_DTR         (1 << 0)

		/** Mask for the RTS handshake line for use with the REQ_SetControlLineState class specific request
		 *  from the host, to indicate that theRTS line state should be high.
		 */
		#define CONTROL_LINE_OUT_RTS         (1 << 1)
		
		/** Mask for the DCD handshake line for use with the a NOTIF_SerialState class specific notification
		 *  from the device to the host, to indicate that the DCD line state is currently high.
		 */
		#define CONTROL_LINE_IN_DCD          (1 << 0)

		/** Mask for the DSR handshake line for use with the a NOTIF_SerialState class specific notification
		 *  from the device to the host, to indicate that the DSR line state is currently high.
		 */
		#define CONTROL_LINE_IN_DSR          (1 << 1)

		/** Mask for the BREAK handshake line for use with the a NOTIF_SerialState class specific notification
		 *  from the device to the host, to indicate that the BREAK line state is currently high.
		 */
		#define CONTROL_LINE_IN_BREAK        (1 << 2)

		/** Mask for the RING handshake line for use with the a NOTIF_SerialState class specific notification
		 *  from the device to the host, to indicate that the RING line state is currently high.
		 */
		#define CONTROL_LINE_IN_RING         (1 << 3)

		/** Mask for use with the a NOTIF_SerialState class specific notification from the device to the host,
		 *  to indicate that a framing error has occurred on the virtual serial port.
		 */
		#define CONTROL_LINE_IN_FRAMEERROR   (1 << 4)

		/** Mask for use with the a NOTIF_SerialState class specific notification from the device to the host,
		 *  to indicate that a parity error has occurred on the virtual serial port.
		 */
		#define CONTROL_LINE_IN_PARITYERROR  (1 << 5)
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
